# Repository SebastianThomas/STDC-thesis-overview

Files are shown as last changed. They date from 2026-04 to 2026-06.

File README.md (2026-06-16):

# Linear-Exponential Algorithm-based Open Source Dive Computer

## Cloning this repository

To ensure all submodules are available locally, use the following command to 
check out the files: 

```bash
git clone --recurse-submodules git@git.ee.ethz.ch:pbl/FS2026/sebastian_thomas_653.git
```

## File Structure

```bash
.
├── 01_report
├── 02_presentation
├── KiCad
├── STDC_C
├── STDC-Ordering
├── STDC-Ordering.zip
├── STDC-STM32-rs
├── STDC-thalmann
└── README.md
```

## The `STDC-STM32-rs` project

This is the embedded firmware implementation, it is the module required to 
reproduce the experimental results, and to run the firmware on the PCB. 

### Setup environment

1. [Install Rust](https://rust-lang.org/tools/install/)
2. [Install just](https://just.systems/man/en/installation.html)
3. Add target for the embedded STM32 environment: `rustup target add thumbv7em-none-eabihf`

### Running code

It contains a `DEBUGGING.md` file with all the necessary information to debug
an application on the PCB and reproduce simulation results.

A `Justfile` is provided for convenience, it contains all required commands for
simulation, embedding, testing, CI, compiling and checking (without compiling).

It is recommended to use a STM32L476Rxx chip, as this is what the code is
tested on. Power it using a 3.7V fixed DC power supply. Attach the STLink V3
to the computer and debug JTAG pads exposed next to the MCU on the PCB, and 
run any `just` recipe that embeds software onto the MCU. After flashing, a 
terminal window will popup on top of the current session.

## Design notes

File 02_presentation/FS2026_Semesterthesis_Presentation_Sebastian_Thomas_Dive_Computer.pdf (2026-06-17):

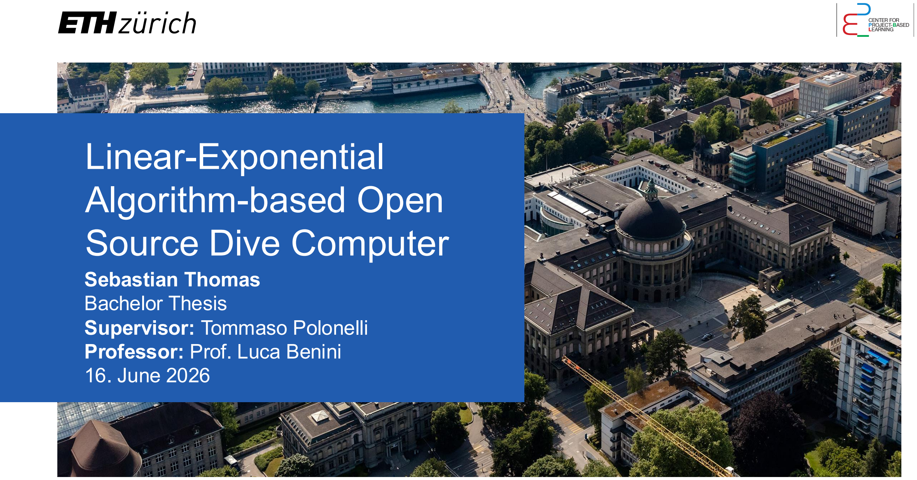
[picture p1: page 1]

# Linear-Exponential Algorithm-based Open Source Dive Computer

# Sebastian Thomas Bachelor Thesis Supervisor: Tommaso Polonelli Professor: Prof. Luca Benini 16. June 2026

# Introduction: Diving & Hyperbaric Environments

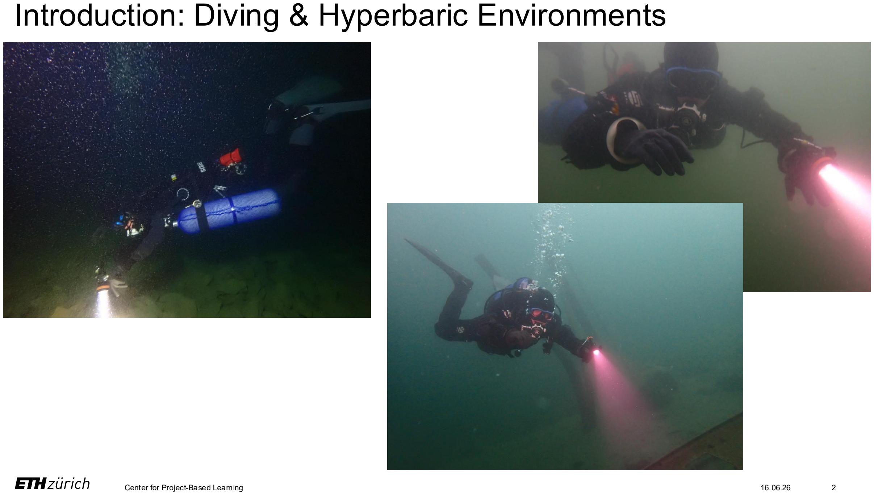
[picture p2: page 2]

Center for Project-Based Learning | 16.06.26 | 2

# Introduction: Diving & Hyperbaric Environments

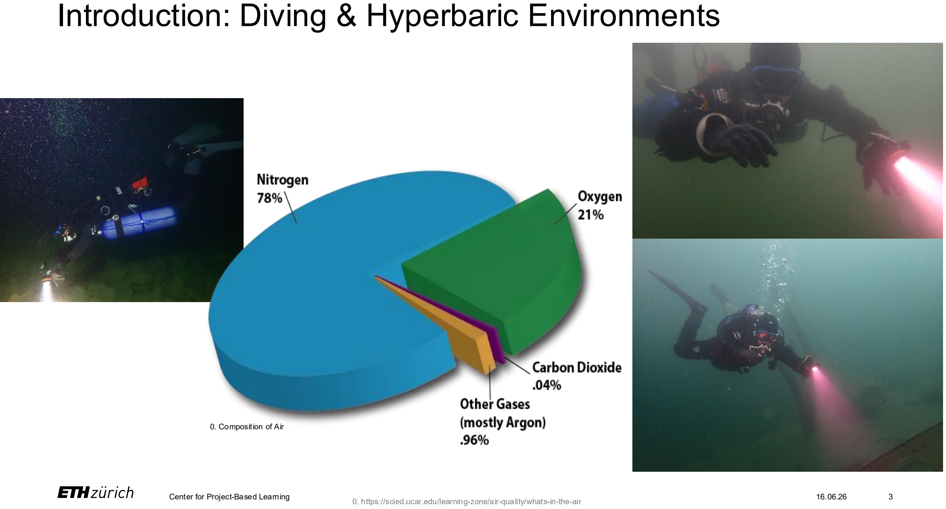
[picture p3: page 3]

0. Composition of Air
0. https://scied.ucar.edu/learning-zone/air-quality/whats-in-the-air

# Introduction: Dive Computers

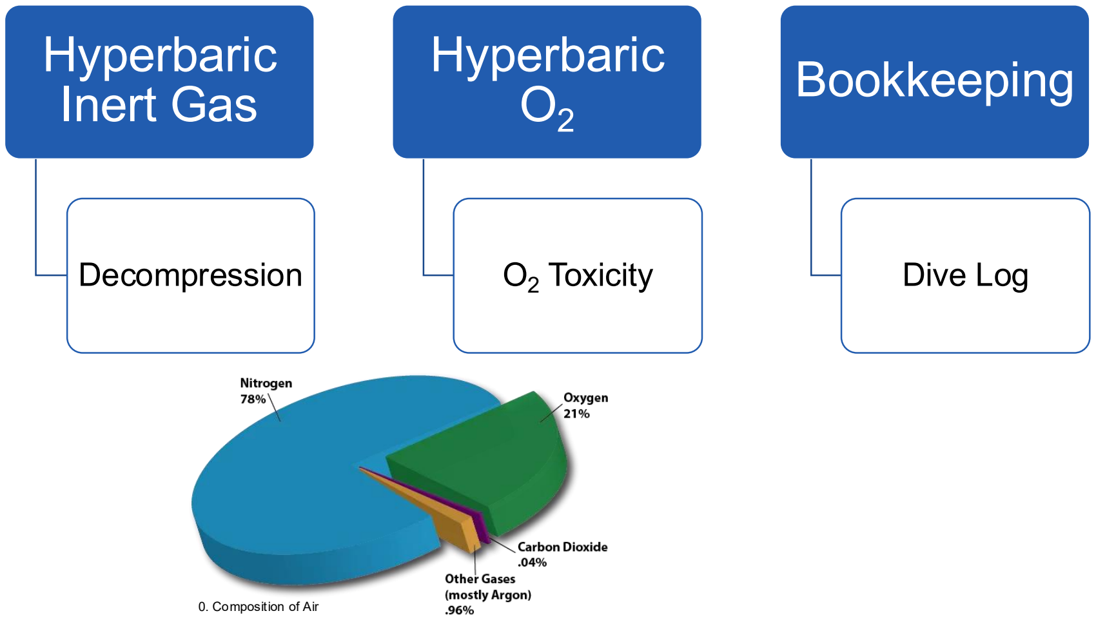
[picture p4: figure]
Hyperbaric Inert Gas; Decompression; Hyperbaric O2; O2 Toxicity; Bookkeeping; Dive Log; 0. Composition of Air

0. https://scied.ucar.edu/learning-zone/air-quality/whats-in-the-air

# Introduction: Dive Computers

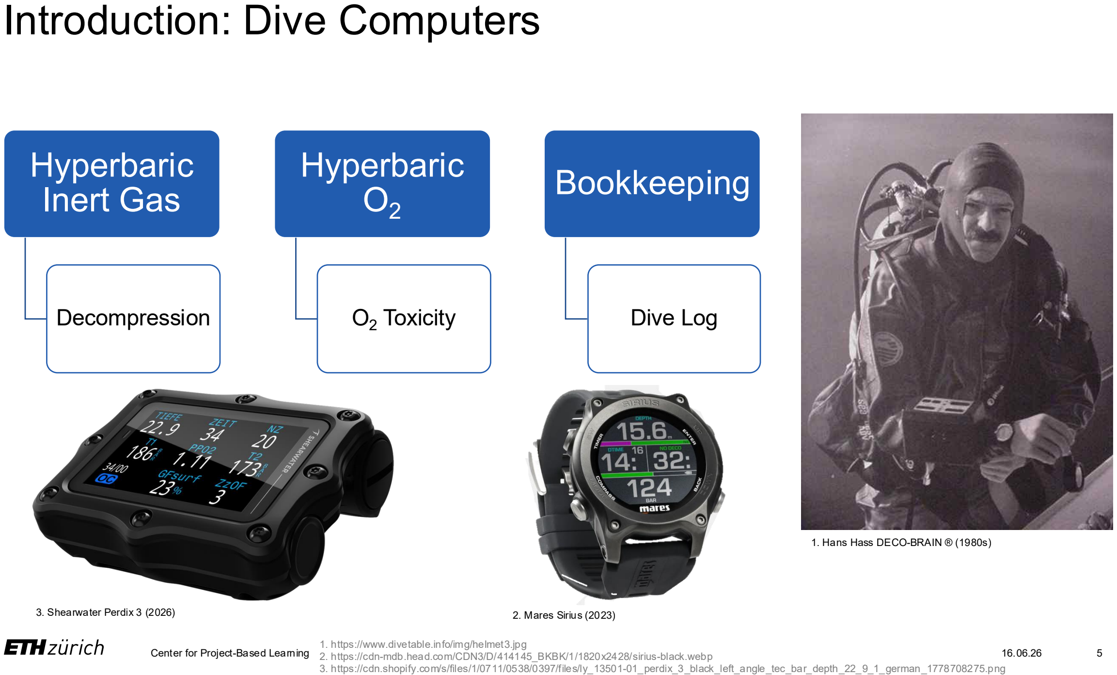
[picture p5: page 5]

# Hyperbaric Inert Gas

# Decompression

# Hyperbaric

O2

# O2 Toxicity

# Bookkeeping

# Dive Log

1. Hans Hass DECO-BRAIN ® (1980s)
2. Mares Sirius (2023)
1. https://www.divetable.info/img/helmet3.jpg
2. https://cdn-mdb.head.com/CDN3/D/414145_BKBK/1/1820x2428/sirius-black.webp
3. https://cdn.shopify.com/s/files/1/0711/0538/0397/files/ly_13501-01_perdix_3_black_left_angle_tec_bar_depth_22_9_1_german_1778708275.png
3. Shearwater Perdix 3 (2026)

# Problem Description

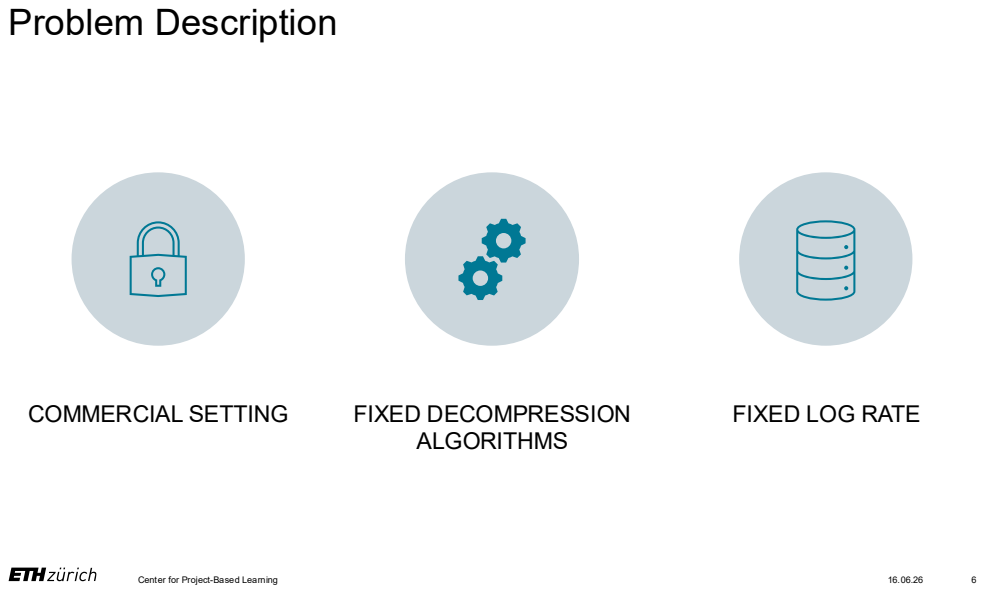
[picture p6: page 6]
COMMERCIAL SETTING; FIXED DECOMPRESSION; ALGORITHMS

FIXED LOG RATE

# Thesis Goals

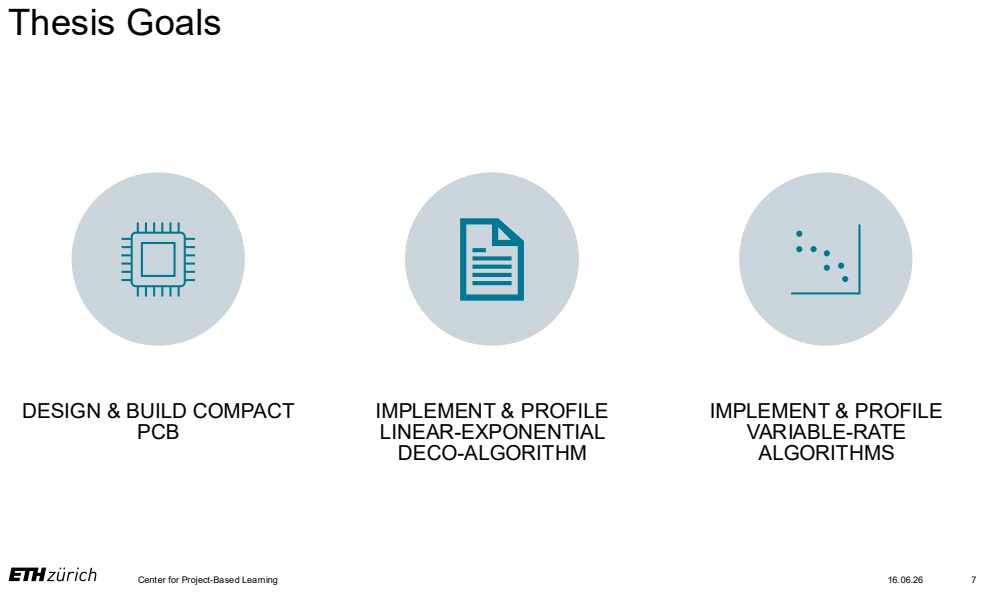
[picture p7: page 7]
PCB; IMPLEMENT & PROFILE LINEAR-EXPONENTIAL DECO-ALGORITHM; IMPLEMENT & PROFILE VARIABLE-RATE ALGORITHMS

DESIGN & BUILD COMPACT

# Background: Decompression Algorithms

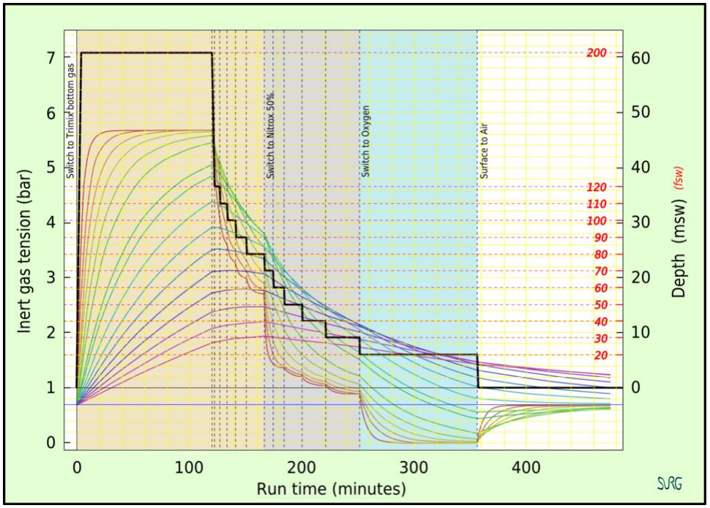
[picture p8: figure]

5. https://en.wikipedia.org/wiki/File:Inert_gas_tensions_in_the_tissue_compartments_during_a_decompression_dive.png
5. Example Decompression Model

# Background: Hyperbaric Environments

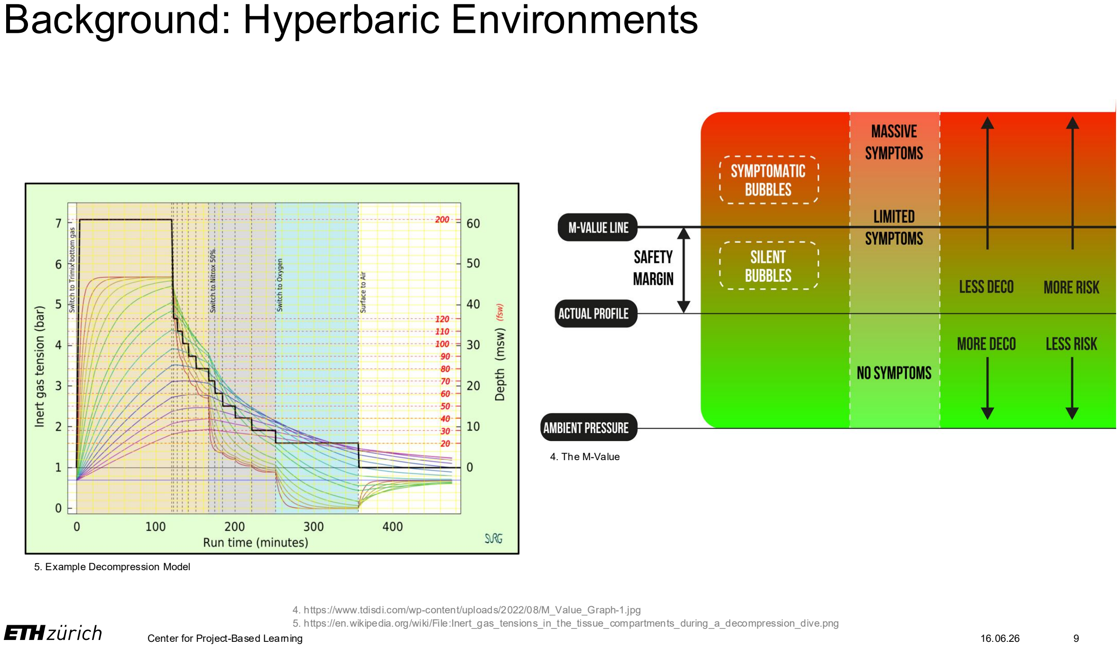
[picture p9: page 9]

4. The M-Value
4. https://www.tdisdi.com/wp-content/uploads/2022/08/M_Value_Graph-1.jpg
5. https://en.wikipedia.org/wiki/File:Inert_gas_tensions_in_the_tissue_compartments_during_a_decompression_dive.png
5. Example Decompression Model

# Implementation

# Implementation: Hardware

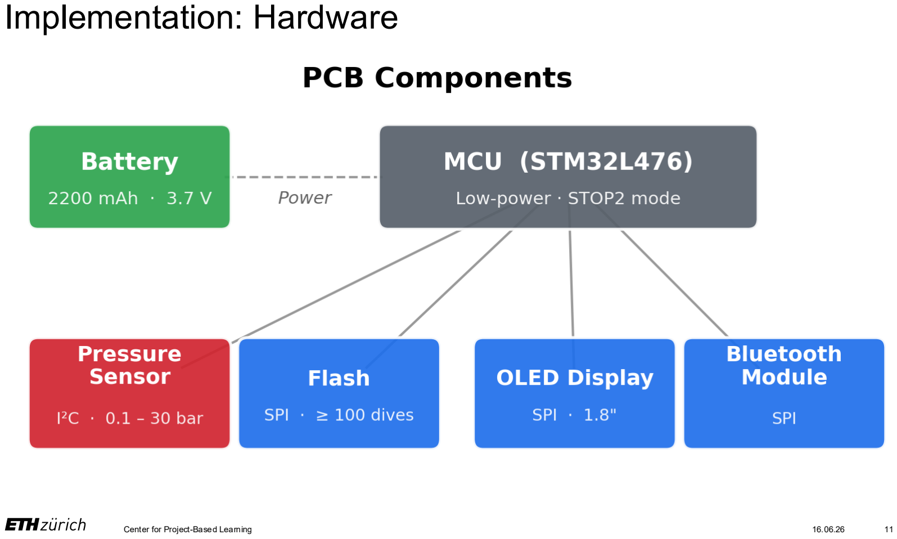
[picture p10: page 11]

# Implementation: Hardware

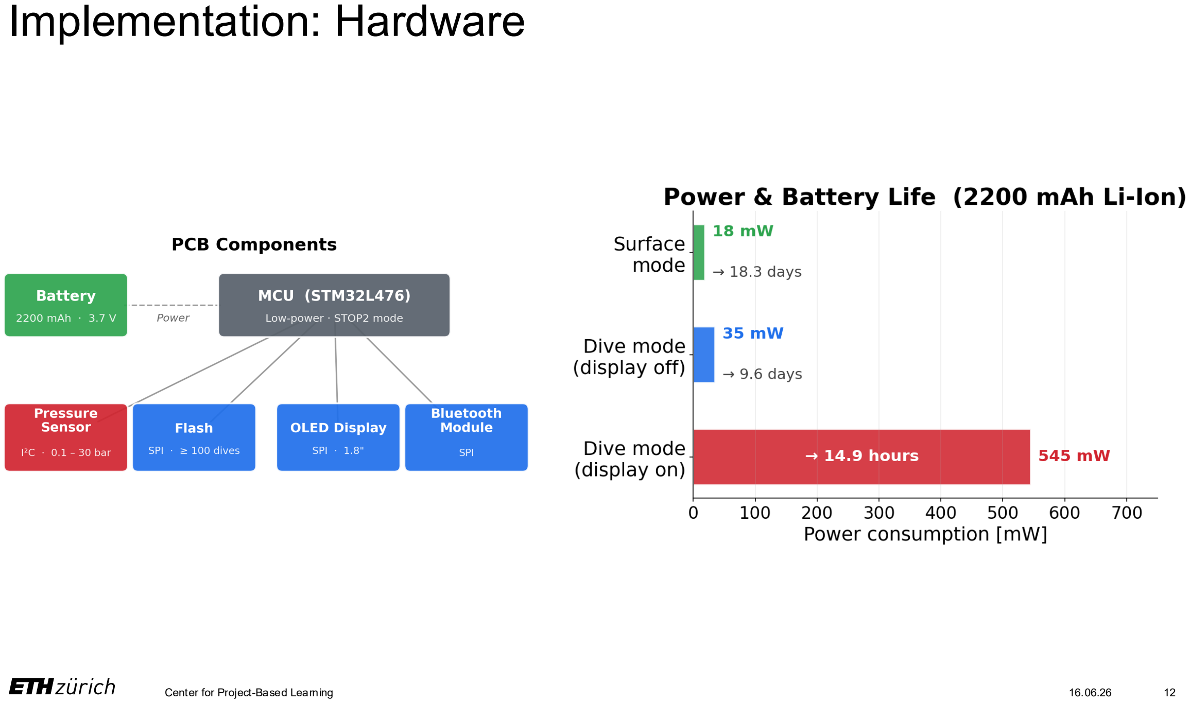
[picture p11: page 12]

# Implementation: Hardware

# - MCU: Low-Power

# - Battery: 18 days / 15 dive hours

# - Pressure sensor: 0.1-30 bar

# - External Bluetooth module

# - Large, bright, OLED display

# - Flash for >100 dives

# MCU

# Battery & Charging

# Pressure Sensor

# BLE

# Display

# Flash

# Implementation: Hardware - Components

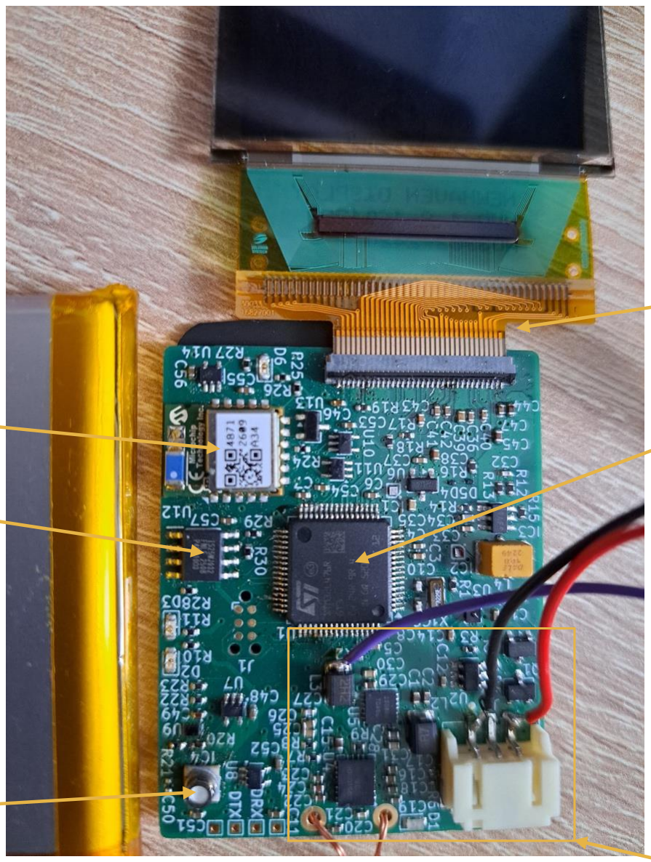
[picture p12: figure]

# - MCU: STM32L476

# - Connector for 3.7V Li-ion battery (2200mAh) − Wireless charging, battery protection

# - MS5849-30BA pressure sensor

# - RN-4871 BLE module

# - 1.8’’ NHD OLED-Display

# - 4MB Flash

# MCU

# Battery & Charging

# Pressure Sensor

# BLE

# Display

# Flash

# Implementation: Hardware – Power Distribution

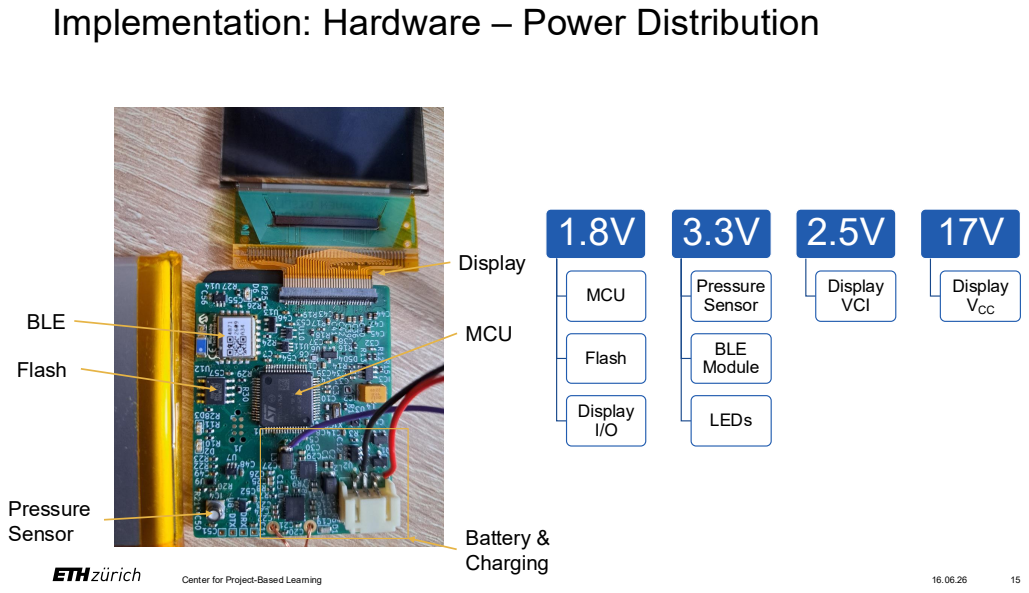
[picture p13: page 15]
MCU; Flash; Display I/O; Pressure Sensor; BLE Module; LEDs; Display VCI; Display; VCC; Battery & Charging; BLE

# Implementation: PCB Layout

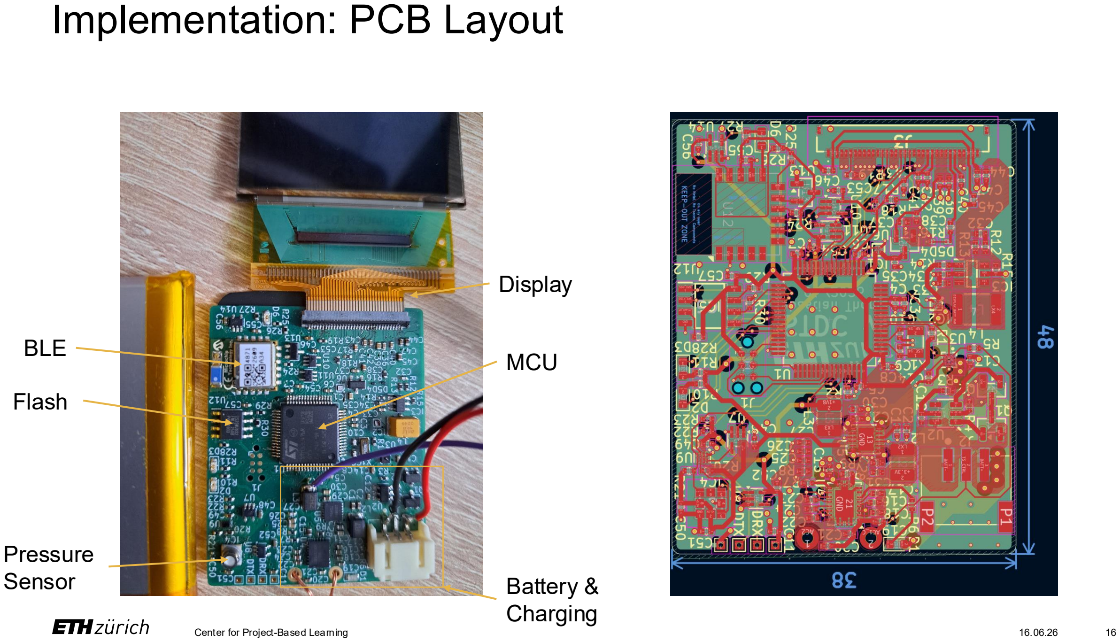
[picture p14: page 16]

# MCU

# Battery & Charging

# Pressure Sensor

# BLE

# Display

# Flash

# Example: Acrylic Enclosure

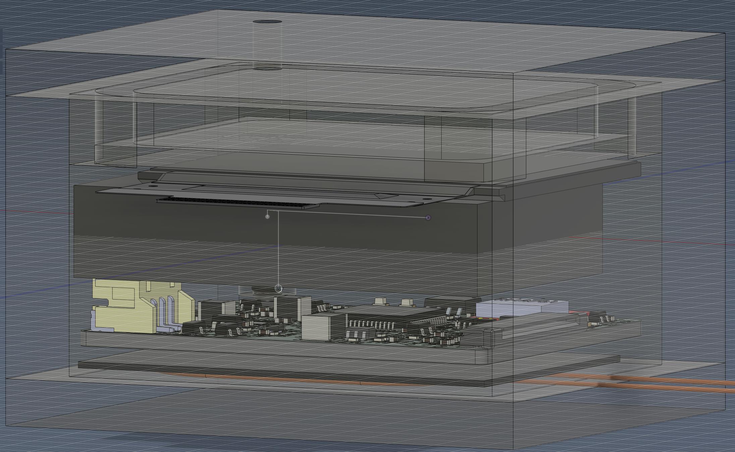
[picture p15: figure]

# Implementation: Linear-Exponential decompression algorithm

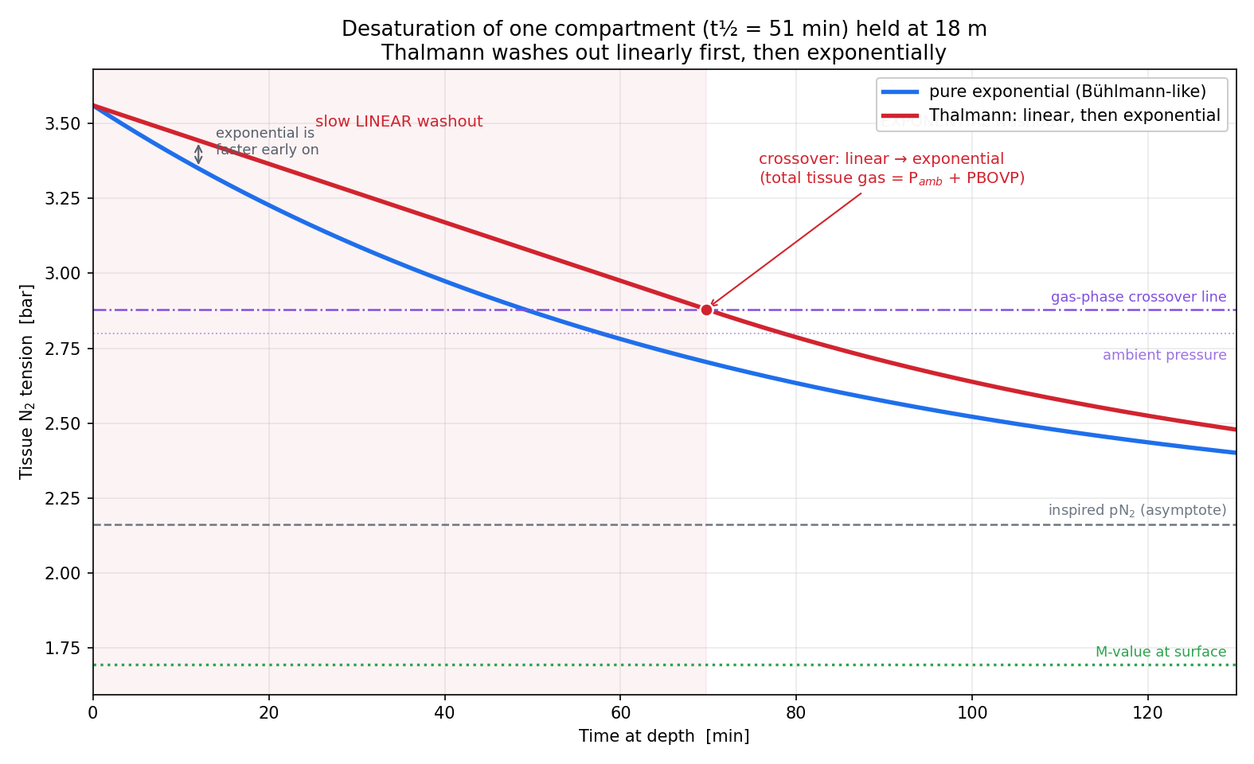
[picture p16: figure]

# Implementation: Variable-rate algorithms

# - Additive Increase (AI), Multiplicative Decrease (MD – change)

| DiffAimdRateAlgorithm | DynamicDiffAimdRateAlgorithm
change | δv δt | δv δt or fixed threshold
Cycles | ~1730 | ~1850

# Results & Discussion

# Results: Variable-rate algorithms – decompression models

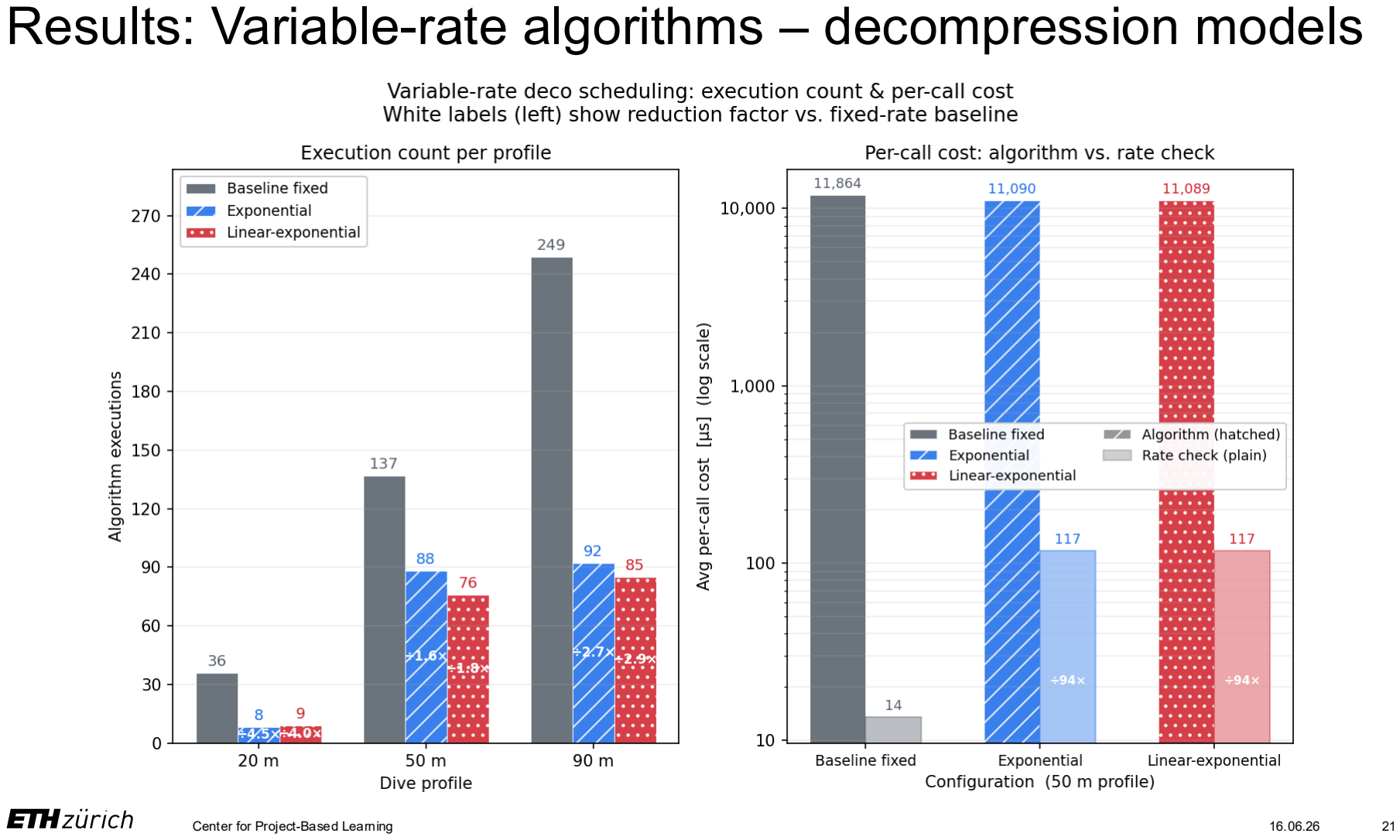
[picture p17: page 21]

# Results: Variable-rate algorithms – O2Tox calculation

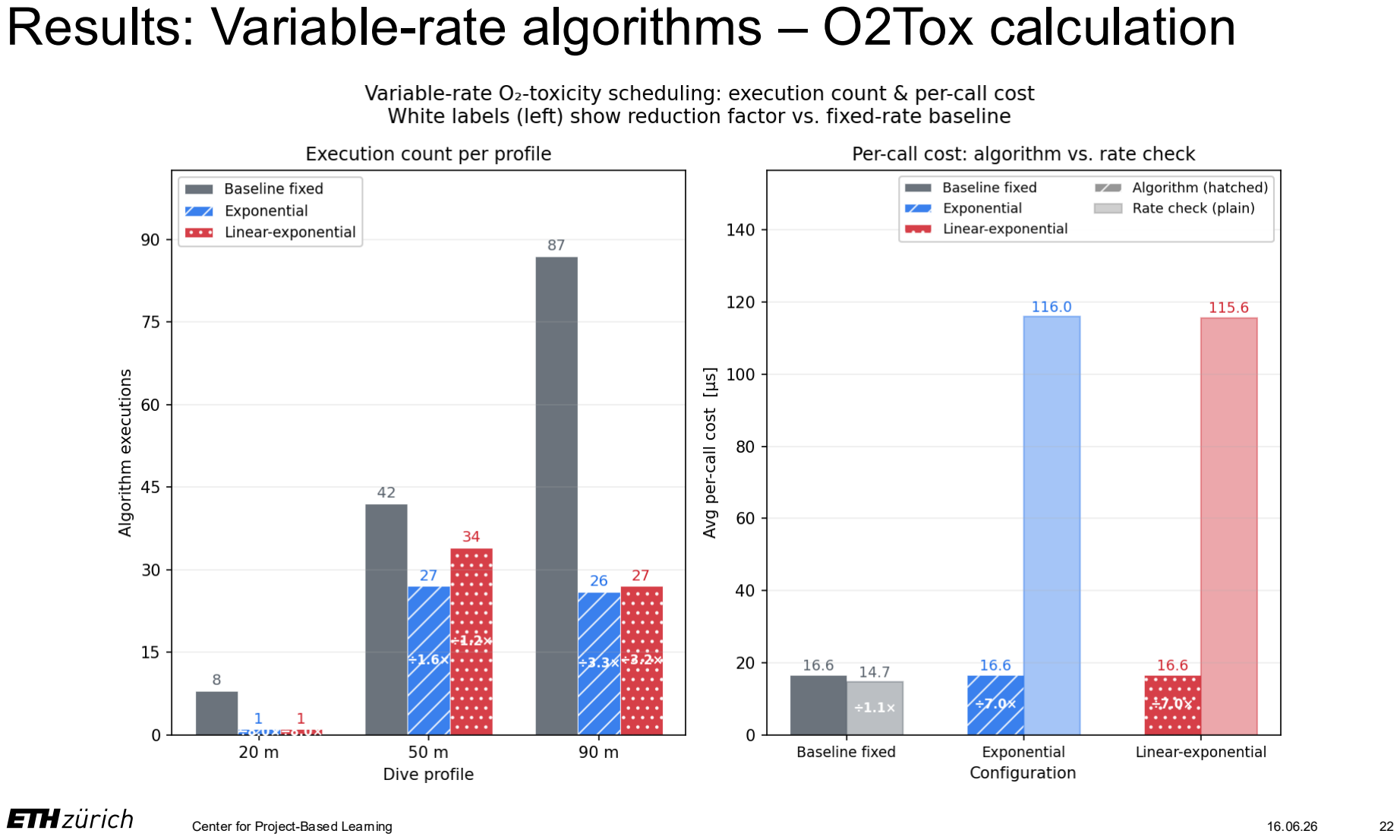
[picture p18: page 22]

# Discussion: Variable-rate for diving algorithms

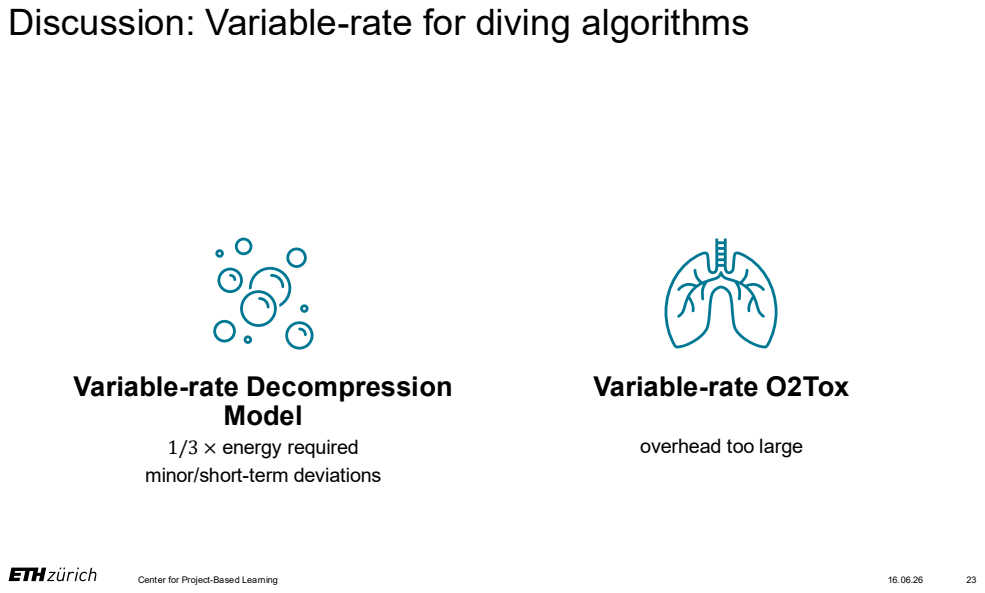
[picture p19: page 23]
Model; Variable-rate O2Tox

Variable-rate Decompression

1 over 3 times
1/3 × energy required
minor/short-term deviations

overhead too large

# Results: Variable-rate algorithms – Dive Log to Flash

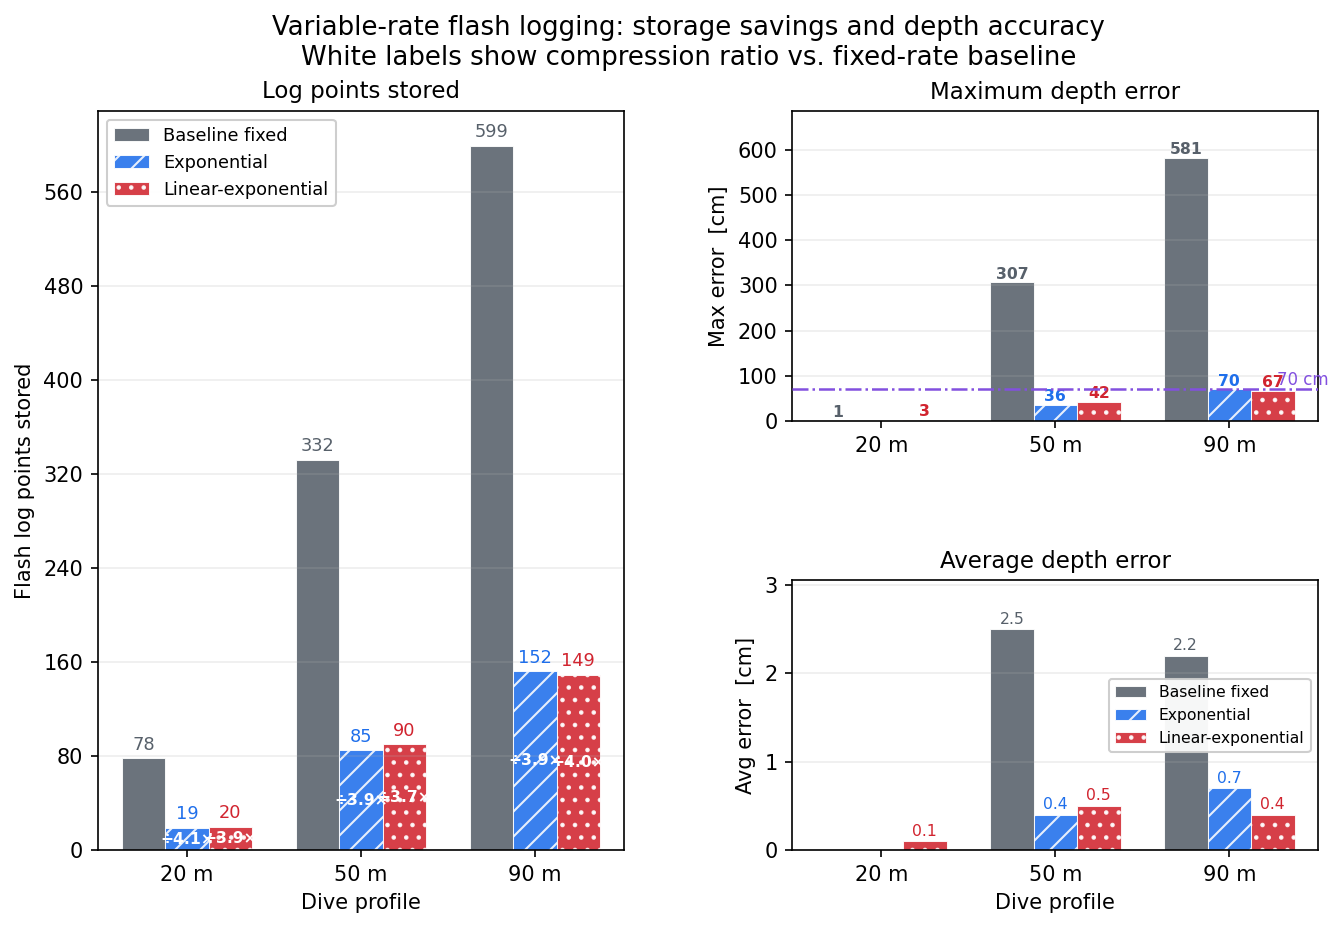
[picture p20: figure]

# Results: Linear-exponential decompression algorithm

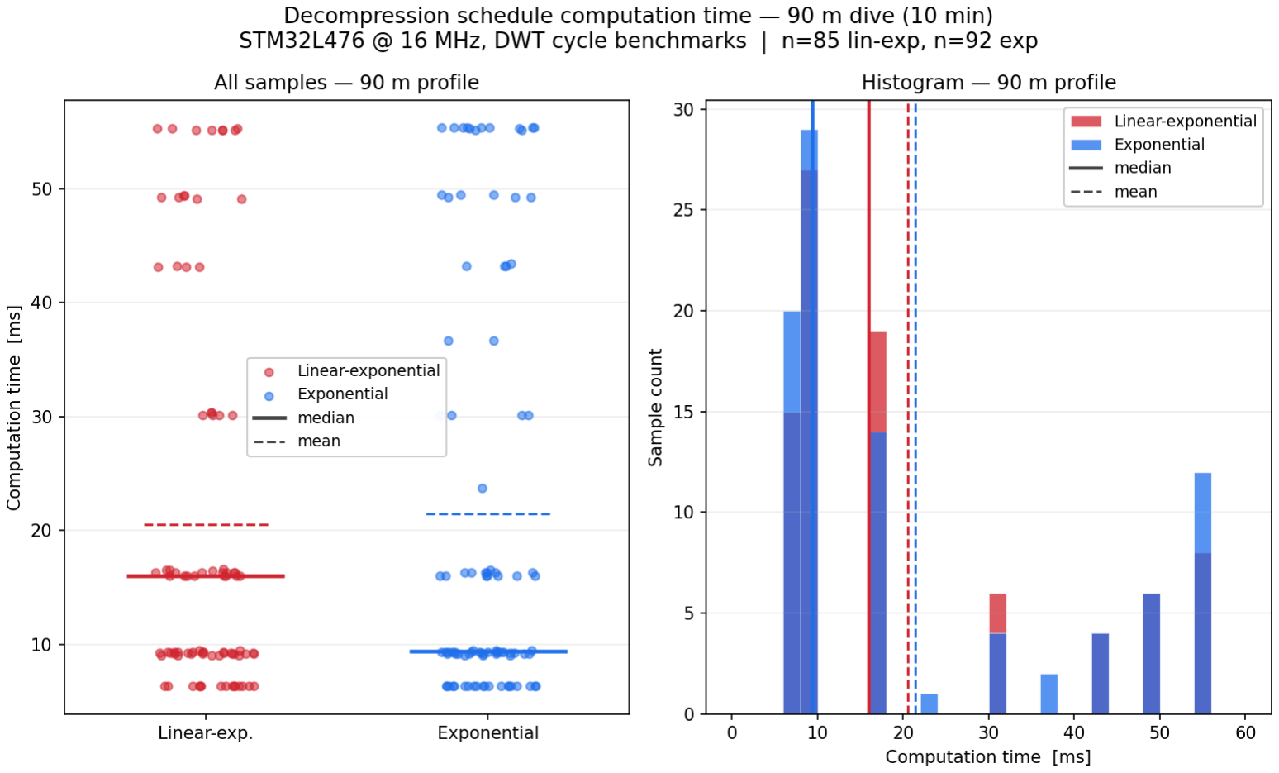
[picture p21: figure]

# Discussion: Linear-exponential algorithms & Variable-rate Flash logging

# - Linear-exponential decompression algorithm − As expected, customizability

# - Variable-rate Dive Log to Flash − Space Reduction: 3.6 ×-4.1 ×

# Conclusion

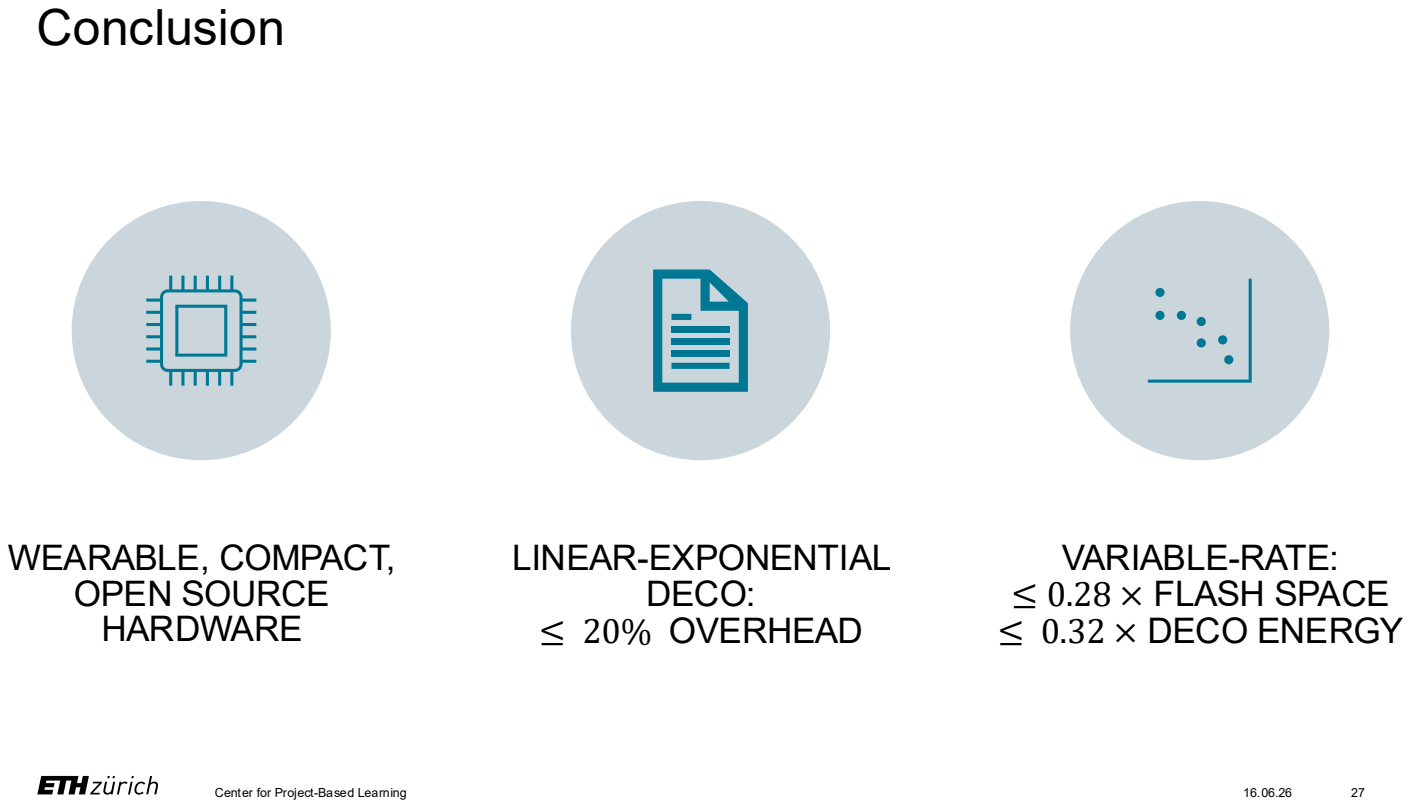
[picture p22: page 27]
WEARABLE, COMPACT, OPEN SOURCE HARDWARE; LINEAR-EXPONENTIAL DECO:

VARIABLE-RATE:
≤ 0.28 × FLASH SPACE
times
≤ 0.32 × DECO ENERGY
less than or equal to , 0.32

less than or equal to 0.28

less than or equal to , 20%
≤ 20% OVERHEAD

# Future Work

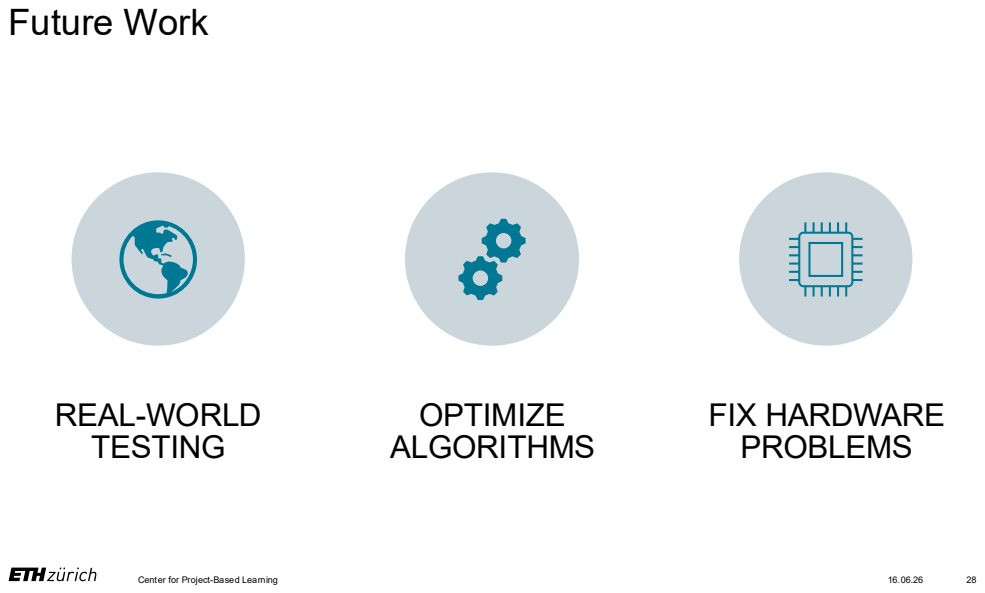
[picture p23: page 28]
REAL-WORLD TESTING; OPTIMIZE ALGORITHMS; FIX HARDWARE PROBLEMS

# Figure References

# Fig. 0. UCAR Center for Science Education, https://scied.ucar.edu/learning-zone/air-

quality/whats (https://scied.ucar.edu/learning-zone/air-quality/whats-in-the-air)- (https://scied.ucar.edu/learning-zone/air-quality/whats-in-the-air)in (https://scied.ucar.edu/learning-zone/air-quality/whats-in-the-air)- (https://scied.ucar.edu/learning-zone/air-quality/whats-in-the-air)the (https://scied.ucar.edu/learning-zone/air-quality/whats-in-the-air)- (https://scied.ucar.edu/learning-zone/air-quality/whats-in-the-air)air, (https://scied.ucar.edu/learning-zone/air-quality/whats-in-the-air) last accessed: 10.06.2026

Fig. 1. Tauch-Simulationssoftware und das D³ Archiv,

# https://www.divetable.info/img/helmet3.jpg, last accessed: 09.06.2026

Fig. 2. Mares (Sirius Black), https://cdn (https://cdn-mdb.head.com/CDN3/D/414145_BKBK/1/1820x2428/sirius-black.webp)-mdb.head.com/CDN3/D/414145_BKBK/1/1820x2428/sirius (https://cdn-mdb.head.com/CDN3/D/414145_BKBK/1/1820x2428/sirius-black.webp)- (https://cdn-mdb.head.com/CDN3/D/414145_BKBK/1/1820x2428/sirius-black.webp)black.webp, (https://cdn-mdb.head.com/CDN3/D/414145_BKBK/1/1820x2428/sirius-black.webp) last accessed: 09.06.2026

Fig. 3. Shearwater Electronics, 2026, https://shearwater.com/en-sw/products/perdix-3, last

# accessed: 09.06.2026

Fig. 4. TDI/SDI: Decompression, 2024, https://www.tdisdi.com/wp (https://www.tdisdi.com/wp-content/uploads/2022/08/M_Value_Graph-1.jpg)-content/uploads/2022/08/M_Value_Graph (https://www.tdisdi.com/wp-content/uploads/2022/08/M_Value_Graph-1.jpg)- (https://www.tdisdi.com/wp-content/uploads/2022/08/M_Value_Graph-1.jpg)1.jpg, (https://www.tdisdi.com/wp-content/uploads/2022/08/M_Value_Graph-1.jpg) last accessed: 08.06.2026

Fig. 5. Wikimedia Foundation: Decompression theory (based on: Eric Maiken, 2004), https://en.wikipedia.org/wiki/File:Inert_gas_tensions_in_the_tissue_compartments_during_a_decompression_dive.png, (https://en.wikipedia.org/wiki/File:Inert_gas_tensions_in_the_tissue_compartments_during_a_decompression_dive.png) last accessed: 09.06.2026

# Sebastian Thomas Bachelor Thesis tsebastian@student.ethz.ch

# ETH Zürich Center for Project-Based Learning ETF F109 Sternwartstrasse 7 8092 Zürich

# www.pbl.ee.ethz.ch

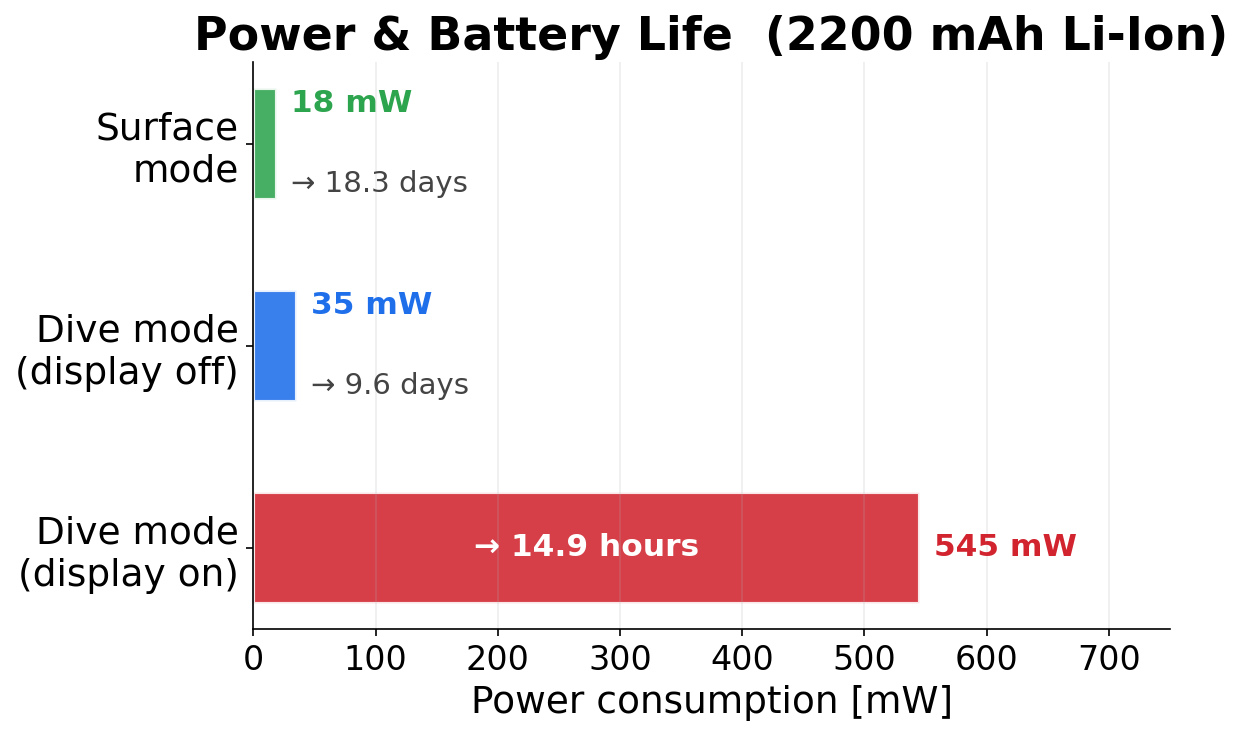
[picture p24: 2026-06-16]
02_presentation/figures/hardware/fig_pcb_power.png

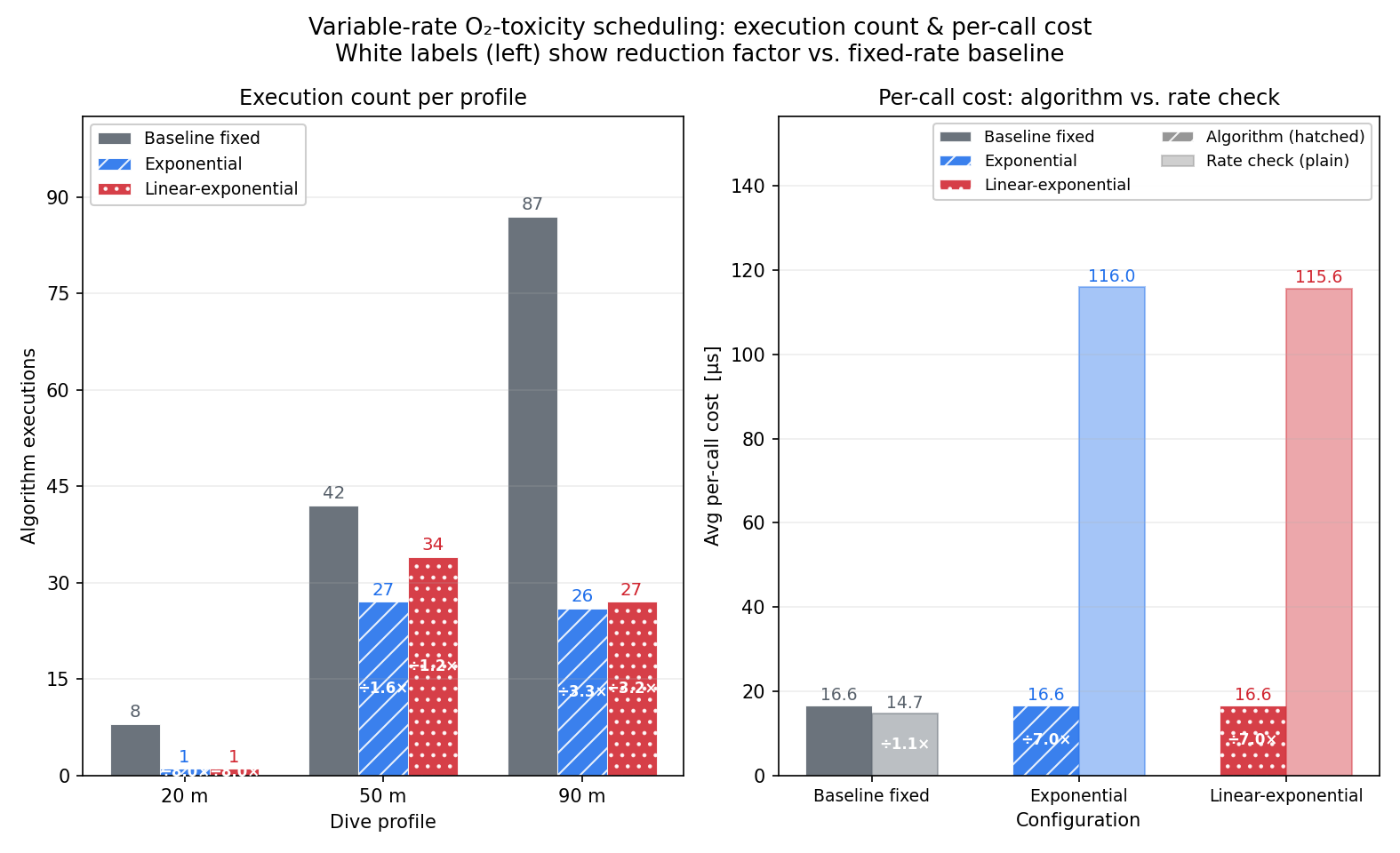
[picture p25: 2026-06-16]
02_presentation/figures/timing/fig_rate_o2tox.png

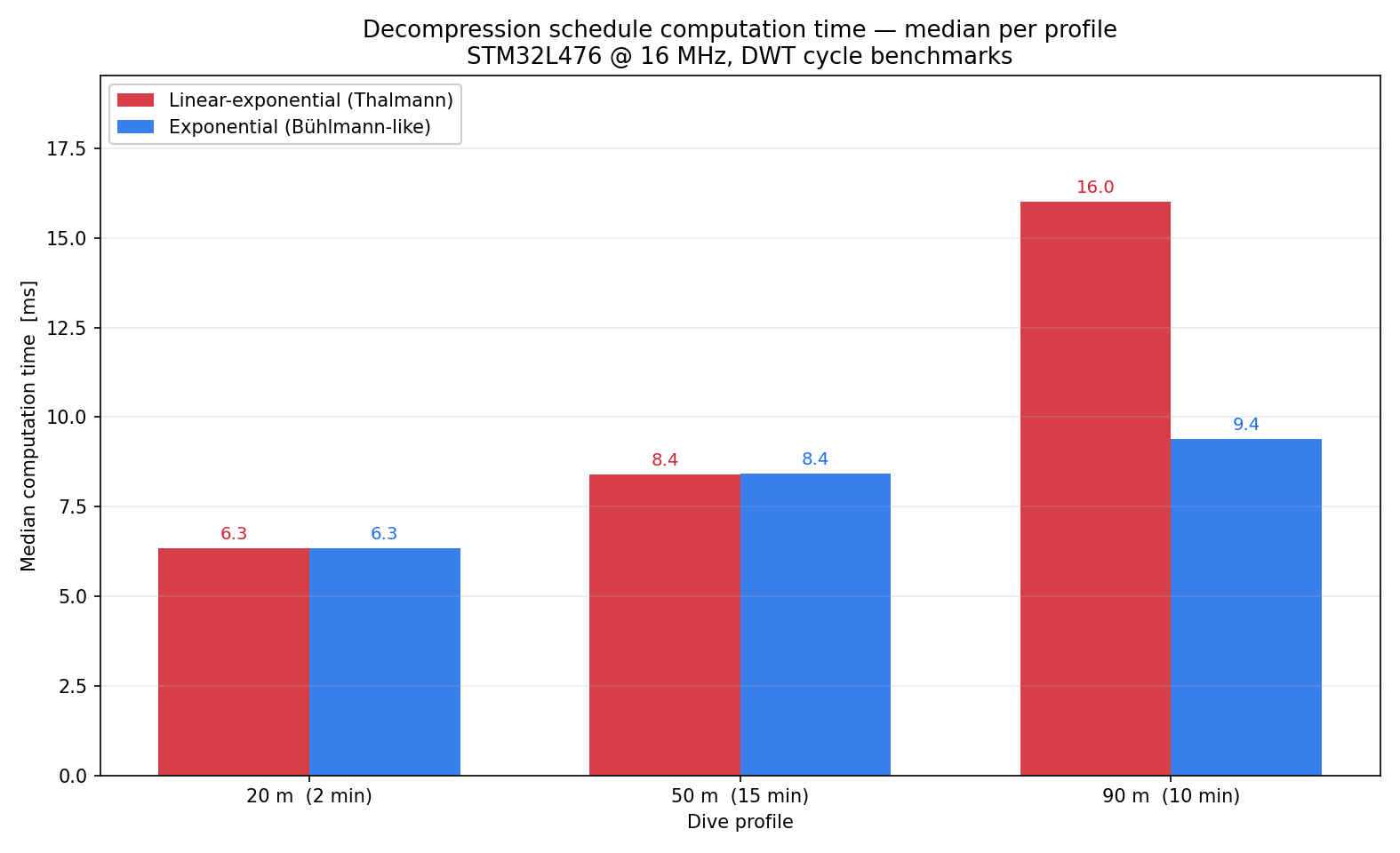
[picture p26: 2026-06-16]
02_presentation/figures/timing/fig_timing_median.png

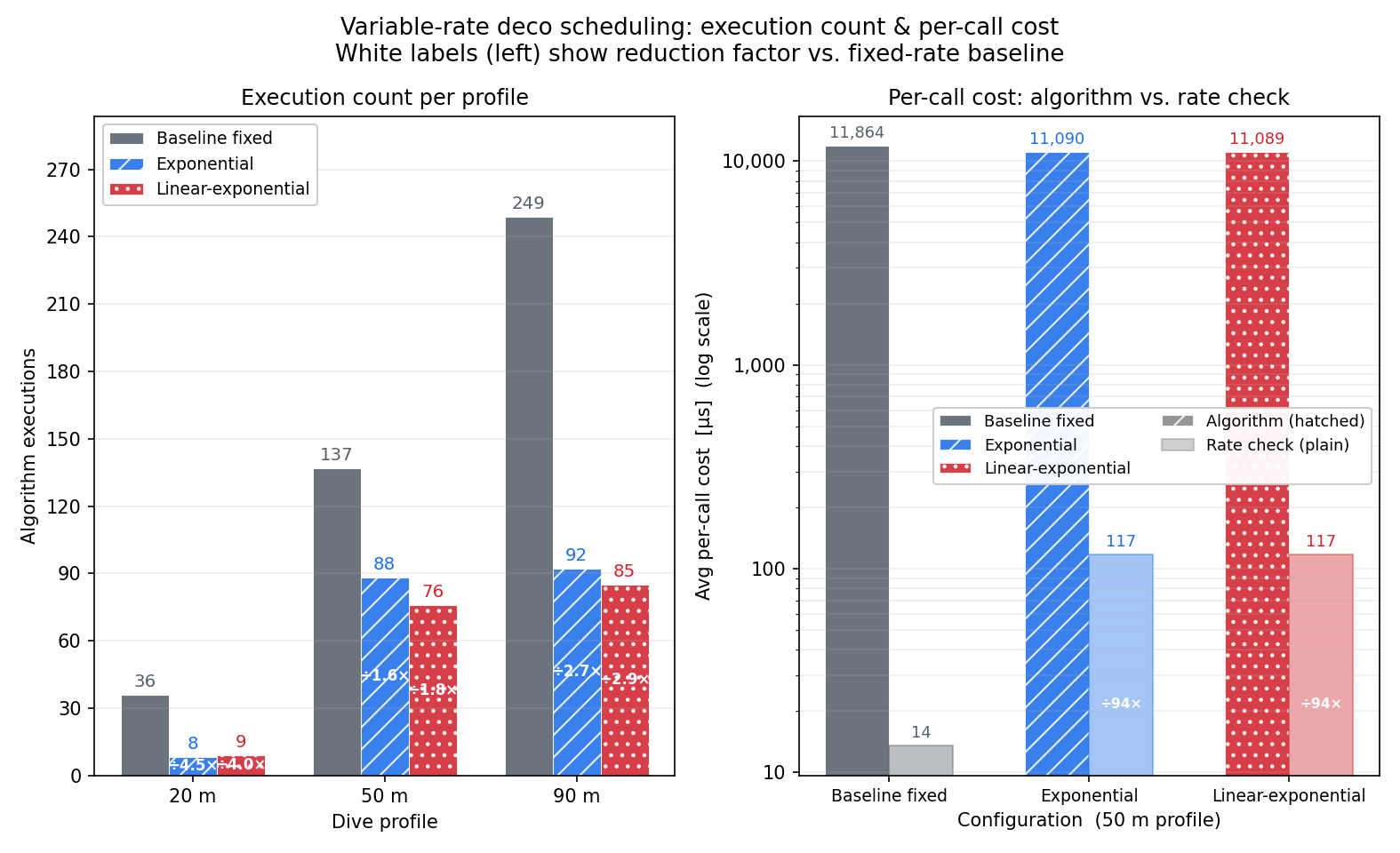
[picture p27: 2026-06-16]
02_presentation/figures/timing/fig_rate_deco.png

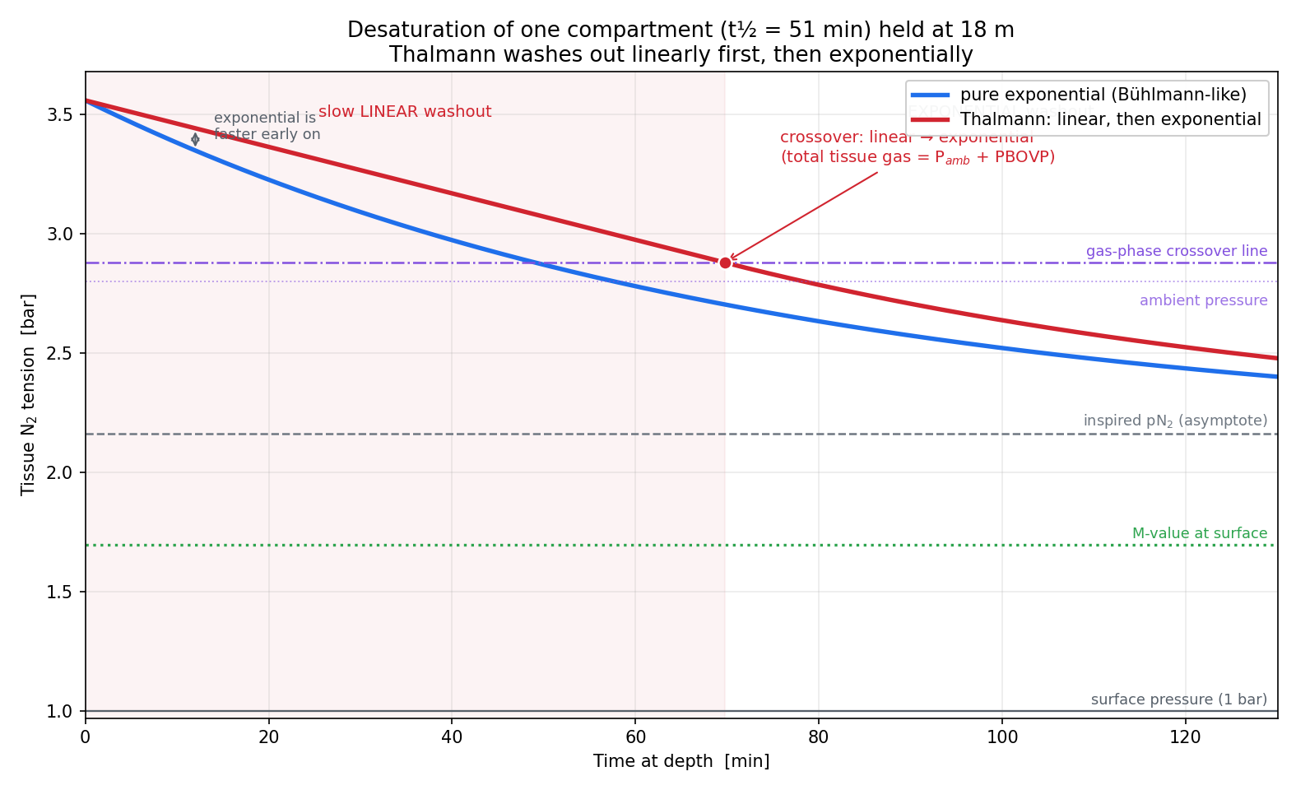
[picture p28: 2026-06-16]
02_presentation/figures/saturation/fig_desat_crossover.png

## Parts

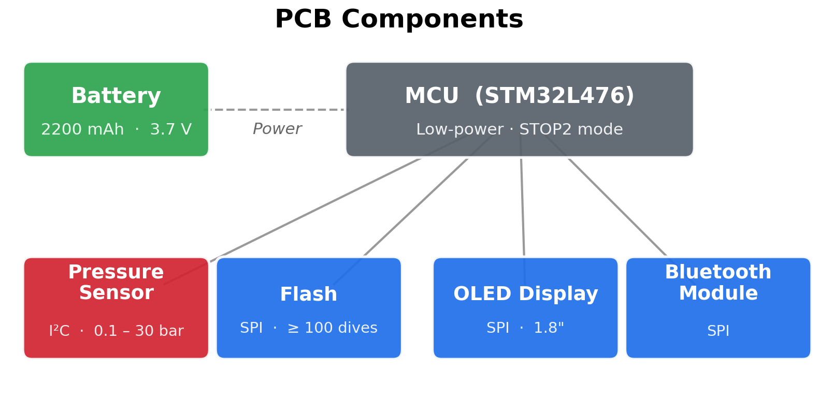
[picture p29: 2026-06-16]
02_presentation/figures/hardware/fig_pcb_components.png

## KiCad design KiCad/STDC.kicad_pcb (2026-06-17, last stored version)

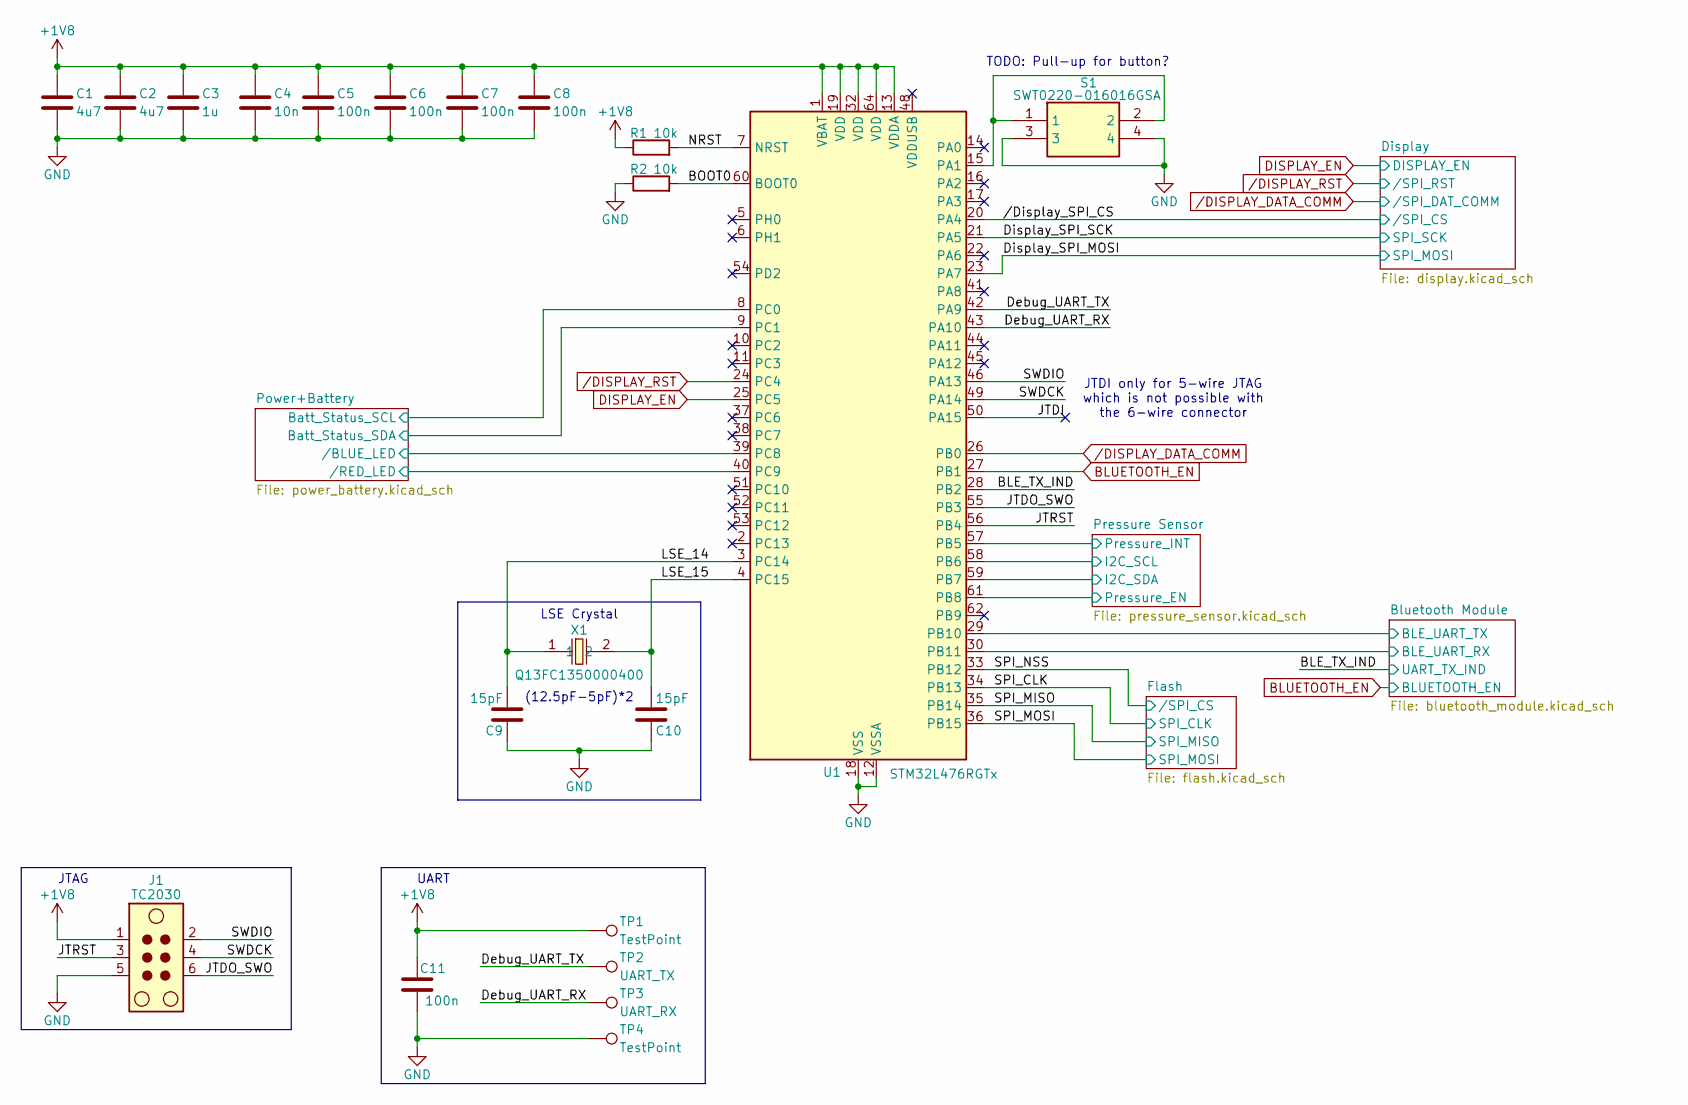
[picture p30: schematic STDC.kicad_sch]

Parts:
C1, C2: 4u7; C_0402_1005Metric
C3: 1u; C_0402_1005Metric
C4: 10n; C_0402_1005Metric
C5, C6, C7, C8, C11: 100n; C_0402_1005Metric
C9, C10: 15pF; C_0402_1005Metric
J1: TC2030; Tag-Connect_TC2030-IDC-NL_2x03_P1.27mm_Vertical
R1, R2: 10k; R_0402_1005Metric
S1: SWT0220-016016GSA; SWT0220016016GSA; Mouser Part Number 640-SWT0220016016GSA
TP1, TP4: TestPoint; TestPoint_THTPad_1.0x1.0mm_Drill0.5mm
TP2: UART_TX; TestPoint_THTPad_1.0x1.0mm_Drill0.5mm
TP3: UART_RX; TestPoint_THTPad_1.0x1.0mm_Drill0.5mm
U1: STM32L476RGTx; LQFP-64_10x10mm_P0.5mm
X1: Q13FC1350000400; Crystal_SMD_3215-2Pin_3.2x1.5mm; LCSC Part C32346

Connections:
+1V8: C1.1, C2.1, C3.1, C4.1, C5.1, C6.1, C7.1, C8.1, C11.1, J1.1, R1.1, TP1.1, U1.1 (VBAT), U1.13 (VDDA), U1.19 (VDD), U1.32 (VDD), U1.64 (VDD); also elsewhere on the board
/BLE_TX_IND: U1.28 (PB2); also elsewhere on the board
/BOOT0: R2.2, U1.60 (BOOT0)
/Bluetooth Module/BLE_UART_RX: U1.30 (PB11); also elsewhere on the board
/Bluetooth Module/BLE_UART_TX: U1.29 (PB10); also elsewhere on the board
/Debug_UART_RX: TP3.1, U1.43 (PA10)
/Debug_UART_TX: TP2.1, U1.42 (PA9)
/Display_SPI_MOSI: U1.23 (PA7); also elsewhere on the board
/Display_SPI_SCK: U1.21 (PA5); also elsewhere on the board
/JTDI: U1.50 (PA15)
/JTDO_SWO: J1.6, U1.55 (PB3)
/JTRST: J1.3, U1.56 (PB4)
/LSE_14: C9.2, U1.3 (PC14), X1.1
/LSE_15: C10.2, U1.4 (PC15), X1.2
/NRST: R1.2, U1.7 (NRST)
/Power+Battery/Batt_Status_SCL: U1.8 (PC0); also elsewhere on the board
/Power+Battery/Batt_Status_SDA: U1.9 (PC1); also elsewhere on the board
/Power+Battery//BLUE_LED: U1.39 (PC8); also elsewhere on the board
/Power+Battery//RED_LED: U1.40 (PC9); also elsewhere on the board
/Pressure Sensor/I2C_SCL: U1.58 (PB6); also elsewhere on the board
/Pressure Sensor/I2C_SDA: U1.59 (PB7); also elsewhere on the board
/Pressure Sensor/Pressure_EN: U1.61 (PB8); also elsewhere on the board
/Pressure Sensor/Pressure_INT: U1.57 (PB5); also elsewhere on the board
/SPI_CLK: U1.34 (PB13); also elsewhere on the board
/SPI_MISO: U1.35 (PB14); also elsewhere on the board
/SPI_MOSI: U1.36 (PB15); also elsewhere on the board
/SPI_NSS: U1.33 (PB12); also elsewhere on the board
/SWDCK: J1.4, U1.49 (PA14)
/SWDIO: J1.2, U1.46 (PA13)
//Display_SPI_CS: U1.20 (PA4); also elsewhere on the board
DISPLAY_EN: U1.25 (PC5); also elsewhere on the board
GND: C1.2, C2.2, C3.2, C4.2, C5.2, C6.2, C7.2, C8.2, C9.1, C10.1, C11.2, J1.5, R2.1, S1.3, S1.4, TP4.1, U1.12 (VSSA), U1.18 (VSS), U1.31 (VSS), U1.47 (VSS), U1.63 (VSS); also elsewhere on the board
unnamed: S1.1, S1.2, U1.15 (PA1)
/DISPLAY_DATA_COMM: U1.26 (PB0); also elsewhere on the board
/DISPLAY_RST: U1.24 (PC4); also elsewhere on the board

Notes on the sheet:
JTDI only for 5-wire JTAG which is not possible with the 6-wire connector
UART
TODO: Pull-up for button?
JTAG
(12.5pF-5pF)*2
LSE Crystal

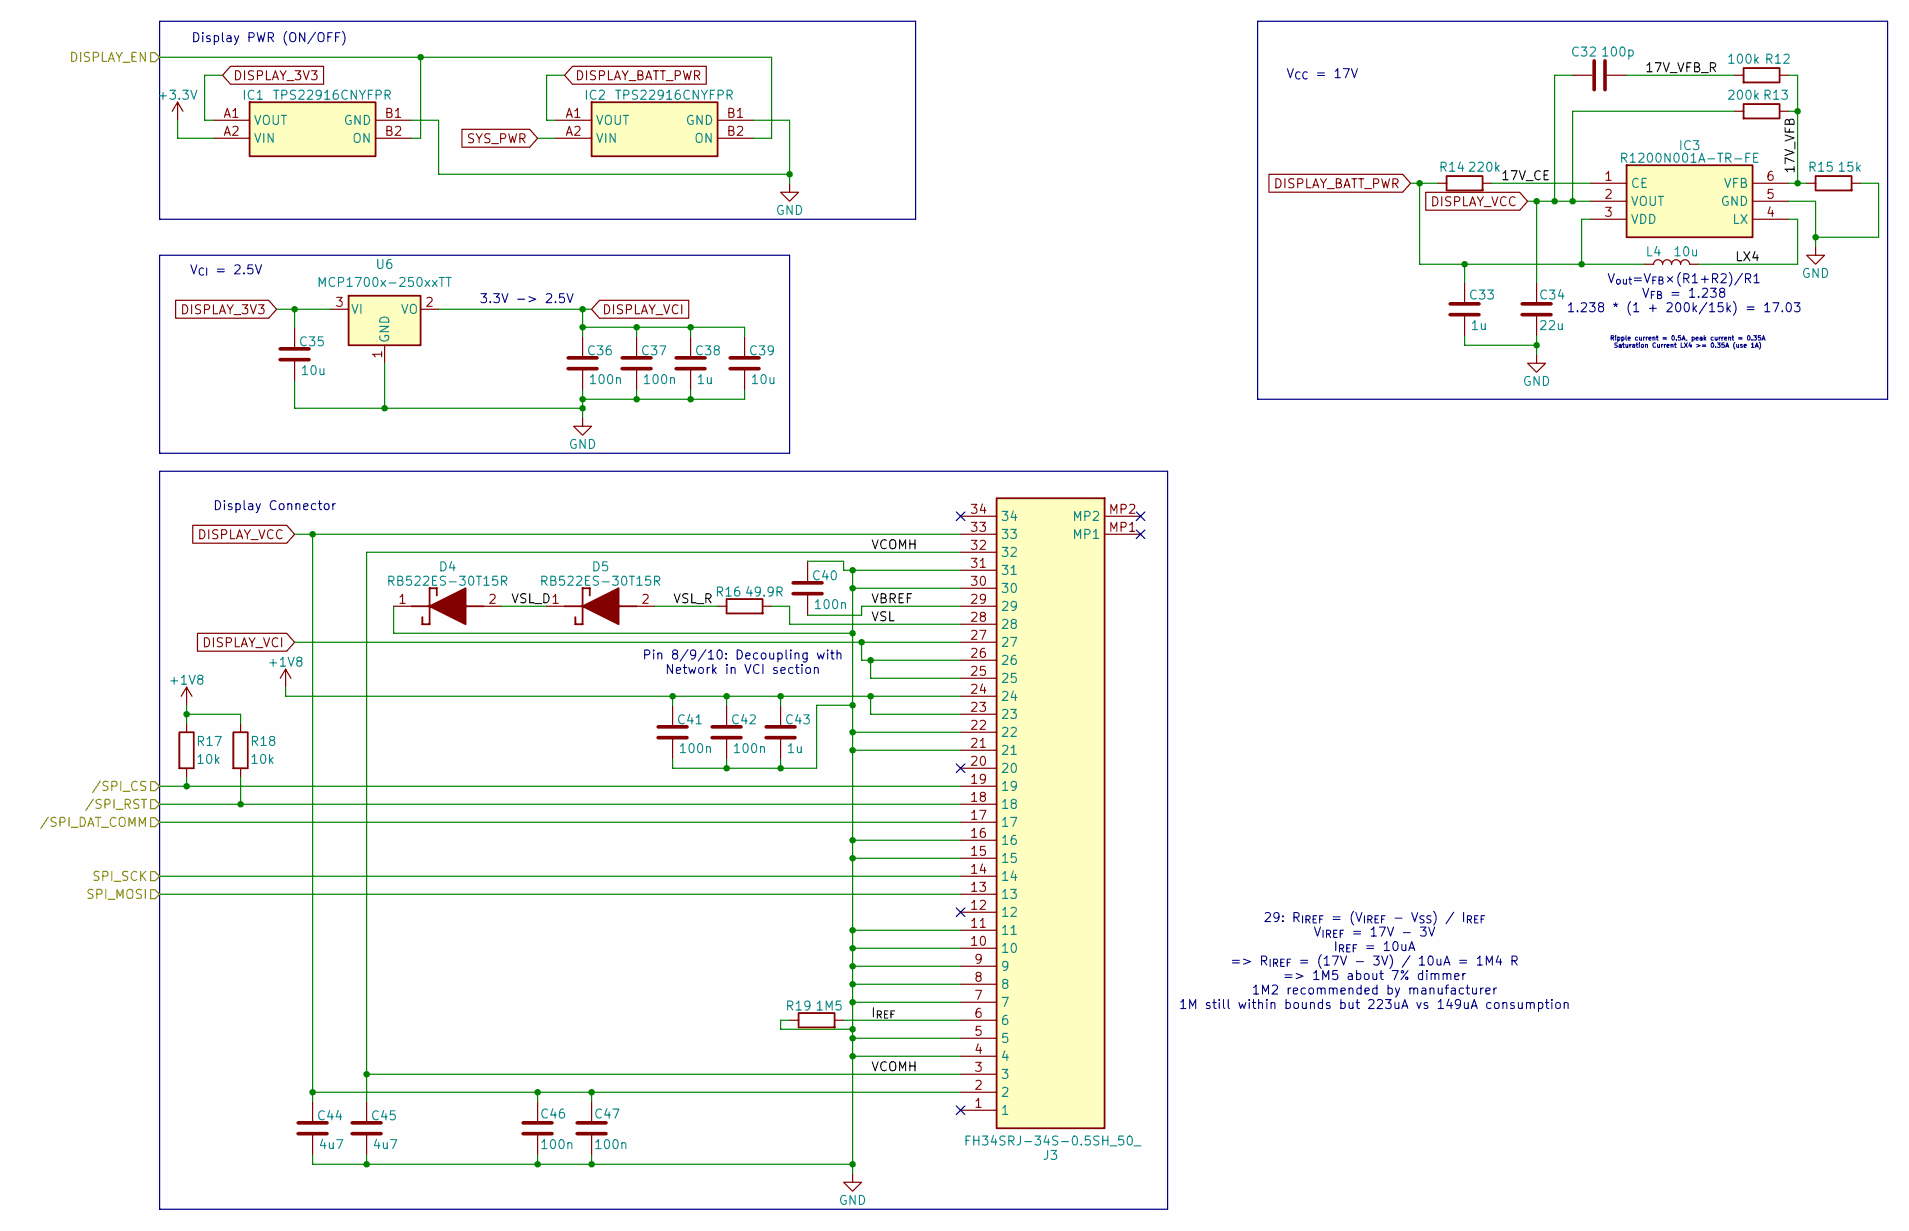
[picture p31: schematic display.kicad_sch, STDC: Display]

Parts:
C32: 100p; C_0402_1005Metric
C33, C38, C43: 1u; C_0402_1005Metric
C34: 22u; C_0402_1005Metric
C35, C39: 10u; C_0402_1005Metric
C36, C37, C40, C41, C42, C46, C47: 100n; C_0402_1005Metric
C44, C45: 4u7; C_0402_1005Metric
D4, D5: RB522ES-30T15R; RB522ES30; Mouser Part Number 755-RB522ES-30T15R
IC1, IC2: TPS22916CNYFPR; BGA4C40P2X2_78X78X50; Mouser Part Number 595-TPS22916CNYFPR
IC3: R1200N001A-TR-FE; SOT95P280X110-6N; Manufacturer_Part_Number R1200N001A-TR-FE
J3: FH34SRJ-34S-0.5SH_50_; FH34SRJ34S05SH50; Mouser Part Number 798-FH34SRJ34S05SH50
L4: 10u; L_1812_4532Metric
R12: 100k; R_0402_1005Metric
R13: 200k; R_0402_1005Metric
R14: 220k; R_0402_1005Metric
R15: 15k; R_0402_1005Metric
R16: 49.9R; R_0402_1005Metric
R17, R18: 10k; R_0402_1005Metric
R19: 1M5; R_0402_1005Metric
U6: MCP1700x-250xxTT; SOT-23

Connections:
+1V8: C41.1, C42.1, C43.1, J3.23, J3.24, R17.1, R18.1; also elsewhere on the board
/Display/17V_CE: IC3.1 (CE), R14.2
/Display/17V_VFB: IC3.6 (VFB), R12.1, R13.1, R15.1
/Display/17V_VFB_R: C32.2, R12.2
/Display/I_{REF}: J3.6, R19.2
/Display/LX4: IC3.4 (LX), L4.2
/Display/VBREF: C40.2, J3.29
/Display/VCOMH: C45.1, J3.3, J3.32
/Display/VSL: J3.28, R16.2
/Display/VSL_D: D4.2 (A), D5.1 (K)
/Display/VSL_R: D5.2 (A), R16.1
/Display_SPI_MOSI: J3.13; also elsewhere on the board
/Display_SPI_SCK: J3.14; also elsewhere on the board
//Display_SPI_CS: J3.19, R17.2; also elsewhere on the board
DISPLAY_3V3: C35.1, IC1.A1 (VOUT), U6.3 (VI)
DISPLAY_BATT_PWR: C33.1, IC2.A1 (VOUT), IC3.3 (VDD), L4.1, R14.1
DISPLAY_EN: IC1.B2 (ON), IC2.B2 (ON); also elsewhere on the board
DISPLAY_VCC: C32.1, C34.1, C44.1, C46.1, C47.1, IC3.2 (VOUT), J3.2, J3.33, R13.2
DISPLAY_VCI: C36.1, C37.1, C38.1, C39.1, J3.25, J3.26, J3.27, U6.2 (VO)
GND: C33.2, C34.2, C35.2, C36.2, C37.2, C38.2, C39.2, C40.1, C41.2, C42.2, C43.2, C44.2, C45.2, C46.2, C47.2, D4.1 (K), IC1.B1 (GND), IC2.B1 (GND), IC3.5 (GND), J3.4, J3.5, J3.7, J3.8, J3.9, J3.10, J3.11, J3.15, J3.16, J3.21, J3.22, J3.30, J3.31, R15.2, R19.1, U6.1 (GND); also elsewhere on the board
SYS_PWR: IC2.A2 (VIN); also elsewhere on the board
/DISPLAY_DATA_COMM: J3.17; also elsewhere on the board
/DISPLAY_RST: J3.18, R18.2; also elsewhere on the board

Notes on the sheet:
Ripple current = 0.5A, peak current = 0.35A Saturation Current LX4 >= 0.35A (use 1A)
Display PWR (ON/OFF)
V_{out}=V_{FB}×(R1+R2)/R1 V_{FB} = 1.238 1.238 * (1 + 200k/15k) = 17.03
Pin 8/9/10: Decoupling with Network in VCI section
3.3V -> 2.5V
Display Connector
29: R_{IREF} = (V_{IREF} - V_{SS}) / I_{REF} V_{IREF} = 17V - 3V I_{REF} = 10uA => R_{IREF} = (17V - 3V) / 10uA = 1M4 R => 1M5 about 7% dimmer 1M2 recommended by manufacturer 1M still within bounds but 223uA vs 149uA consumption
V_{CC} = 17V
V_{CI} = 2.5V

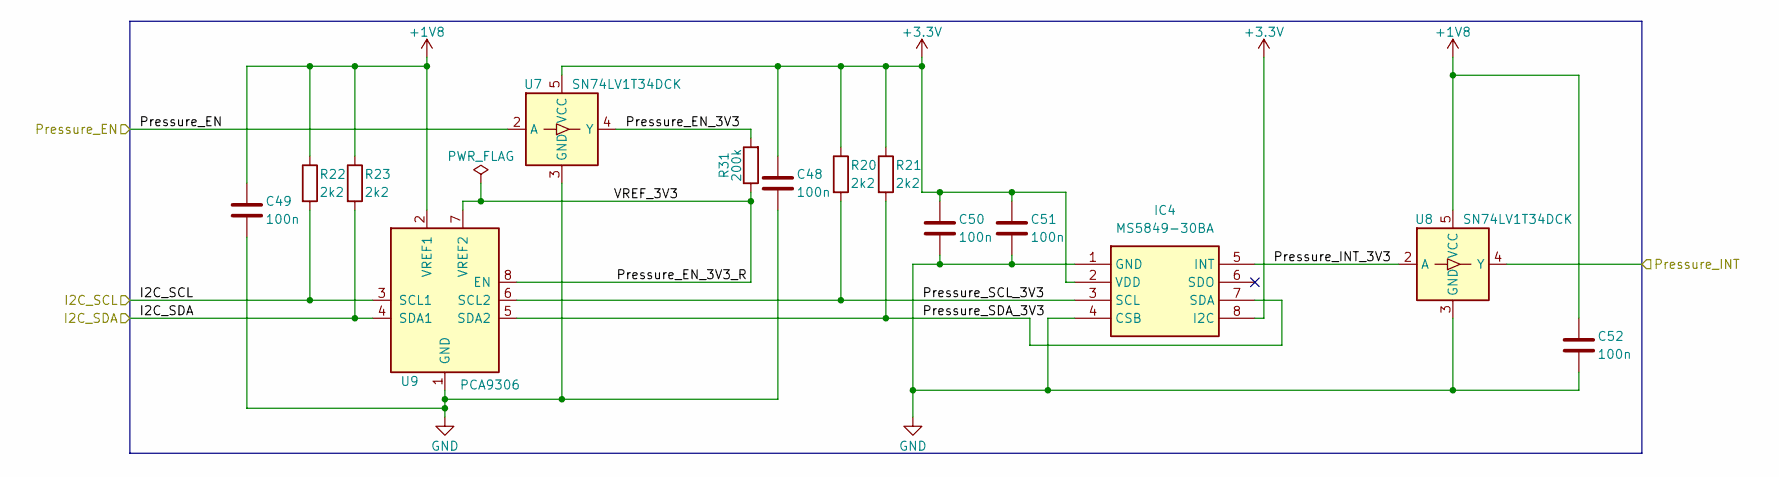
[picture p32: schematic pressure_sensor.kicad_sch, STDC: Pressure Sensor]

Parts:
C48, C49, C50, C51, C52: 100n; C_0402_1005Metric
IC4: MS5849-30BA; MS584930BA; Mouser Part Number 824-MS5849-30BA
R20, R21, R22, R23: 2k2; R_0402_1005Metric
R31: 200k; R_0402_1005Metric
U7, U8: SN74LV1T34DCK; SOT-353_SC-70-5
U9: PCA9306; X2SON-8_1.4x1mm_P0.35mm

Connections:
+1V8: C49.1, C52.1, R22.1, R23.1, U8.5 (VCC), U9.2 (VREF1); also elsewhere on the board
/Pressure Sensor/I2C_SCL: R22.2, U9.3 (SCL1); also elsewhere on the board
/Pressure Sensor/I2C_SDA: R23.2, U9.4 (SDA1); also elsewhere on the board
/Pressure Sensor/Pressure_EN: U7.2 (A); also elsewhere on the board
/Pressure Sensor/Pressure_INT: U8.4 (Y); also elsewhere on the board
/Pressure Sensor/Pressure_INT_3V3: IC4.5 (INT), U8.2 (A)
/Pressure Sensor/Pressure_SCL_3V3: IC4.3 (SCL), R20.2, U9.6 (SCL2)
/Pressure Sensor/Pressure_SDA_3V3: IC4.7 (SDA), R21.2, U9.5 (SDA2)
GND: C48.2, C49.2, C50.2, C51.2, C52.2, IC4.1 (GND), IC4.4 (CSB), U7.3 (GND), U8.3 (GND), U9.1 (GND); also elsewhere on the board

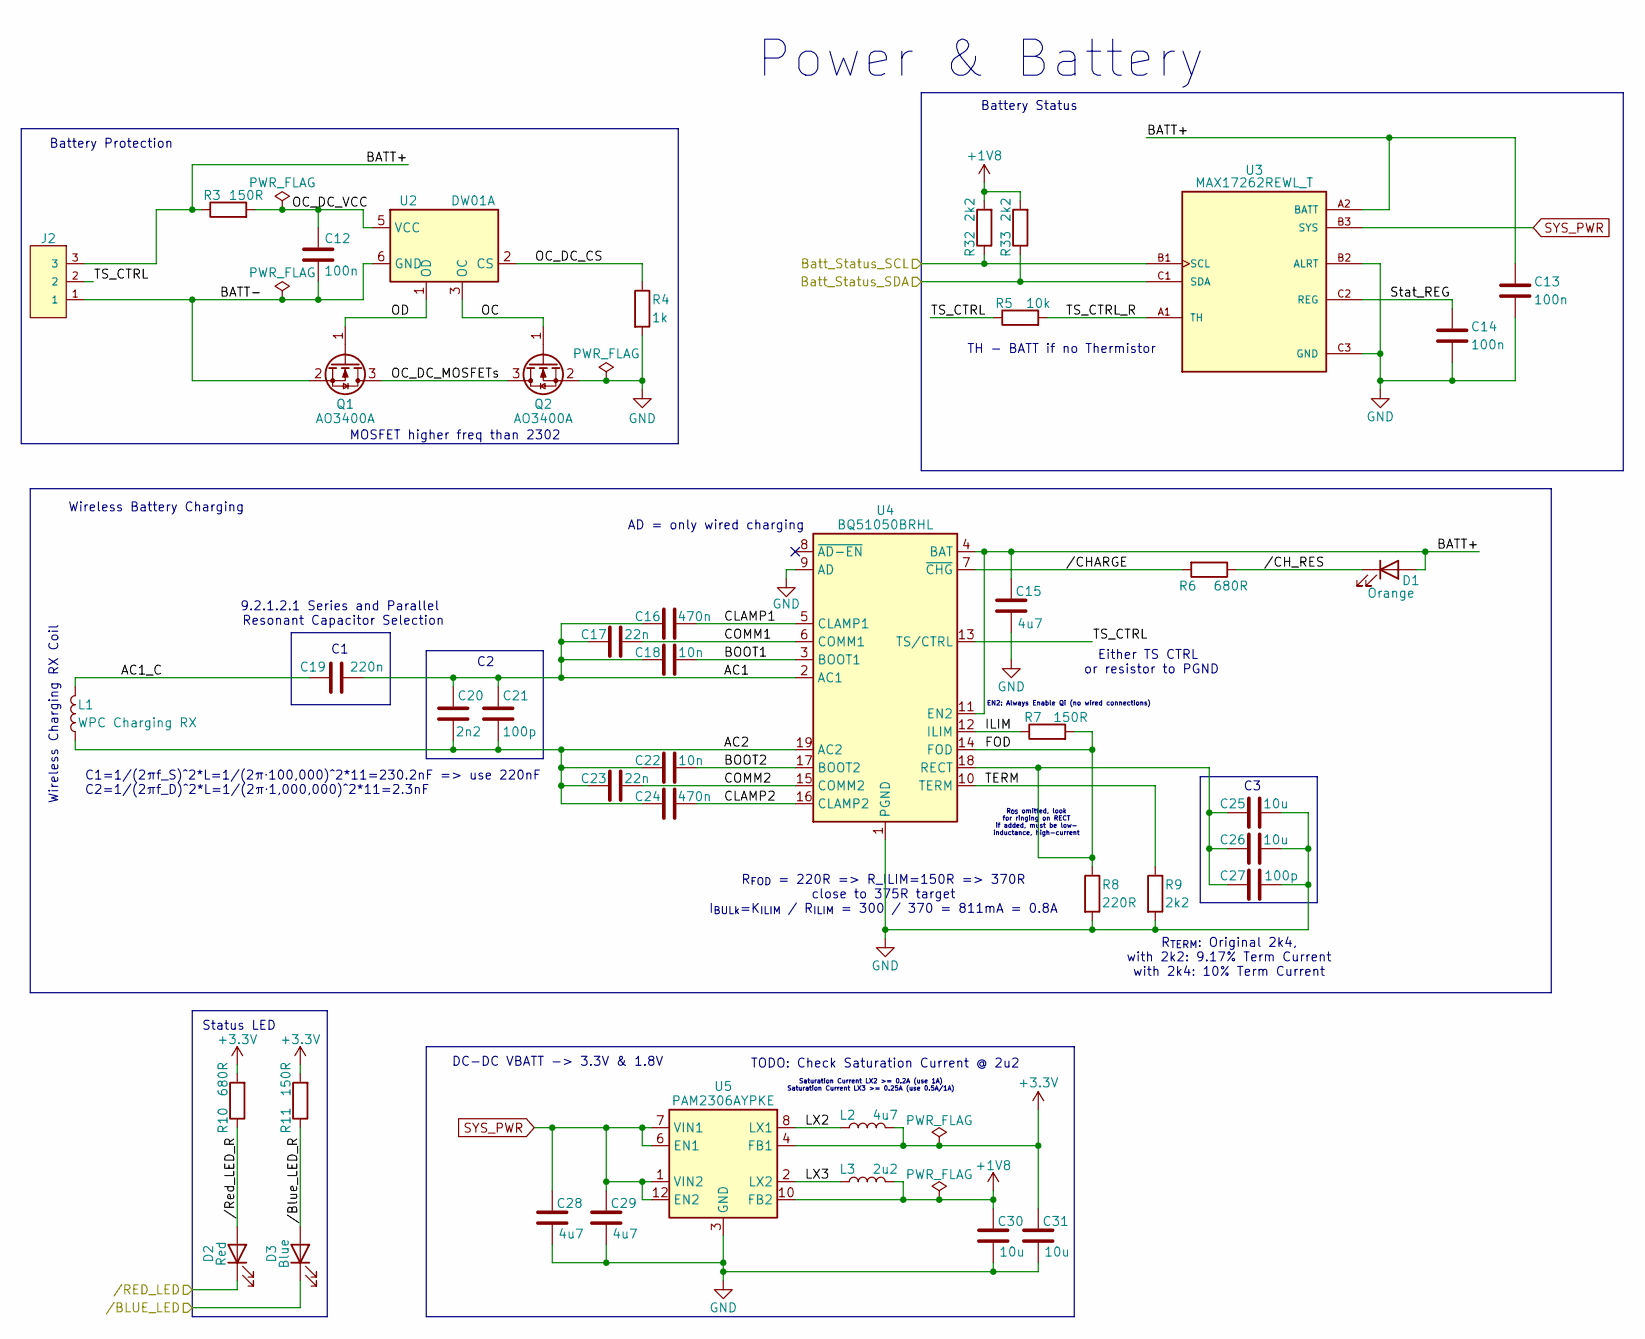
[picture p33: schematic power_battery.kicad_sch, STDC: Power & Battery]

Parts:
C12, C13, C14: 100n; C_0402_1005Metric
C15, C28, C29: 4u7; C_0402_1005Metric
C16, C24: 470n; C_0402_1005Metric
C17, C23: 22n; C_0402_1005Metric
C18, C22: 10n; C_0402_1005Metric
C19: 220n; C_0402_1005Metric
C20: 2n2; C_0402_1005Metric
C21, C27: 100p; C_0402_1005Metric
C25, C26, C30, C31: 10u; C_0402_1005Metric
D1: Orange; LED_0603_1608Metric
D2: Red; LED_0603_1608Metric
D3: Blue; LED_0603_1608Metric
J2: S3B-PH-SM4-TB_LF__SN_; JST_S3B-PH-SM4-TB_LF__SN_; PARTREV NA
L1: WPC Charging RX; L_IWAS4832ABEB110JF1
L2: 4u7; L_1210_3225Metric
L3: 2u2; L_1210_3225Metric
Q1, Q2: AO3400A; SOT-23
R3, R7, R11: 150R; R_0402_1005Metric
R4: 1k; R_0402_1005Metric
R5: 10k; R_0402_1005Metric
R6, R10: 680R; R_0402_1005Metric
R8: 220R; R_0402_1005Metric
R9, R32, R33: 2k2; R_0402_1005Metric
U2: DW01A; SOT-23-6
U3: MAX17262REWL_T; BGA9N40P3X3_144X146X69N
U4: BQ51050BRHL; Texas_VQFN-RHL-20
U5: PAM2306AYPKE; WDFN-12-1EP_3x3mm_P0.45mm_EP1.7x2.5mm

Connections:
+1V8: C30.1, L3.2, R32.2, R33.2, U5.10 (FB2); also elsewhere on the board
/Power+Battery/AC1: C16.1, C17.1, C18.1, C19.2, C20.1, C21.1, U4.2 (AC1)
/Power+Battery/AC1_C: C19.1, L1.2
/Power+Battery/AC2: C20.2, C21.2, C22.1, C23.1, C24.1, L1.1, U4.19 (AC2)
/Power+Battery/BATT+: C13.1, C15.1, D1.2 (A), J2.3, R3.1, U3.A2 (BATT), U4.4 (BAT), U4.11 (EN2)
/Power+Battery/BATT-: C12.2, J2.1, Q1.2 (S), U2.6 (GND)
/Power+Battery/BOOT1: C18.2, U4.3 (BOOT1)
/Power+Battery/BOOT2: C22.2, U4.17 (BOOT2)
/Power+Battery/Batt_Status_SCL: R32.1, U3.B1 (SCL); also elsewhere on the board
/Power+Battery/Batt_Status_SDA: R33.1, U3.C1 (SDA); also elsewhere on the board
/Power+Battery/CLAMP1: C16.2, U4.5 (CLAMP1)
/Power+Battery/CLAMP2: C24.2, U4.16 (CLAMP2)
/Power+Battery/COMM1: C17.2, U4.6 (COMM1)
/Power+Battery/COMM2: C23.2, U4.15 (COMM2)
/Power+Battery/FOD: C25.1, C26.1, C27.1, R7.2, R8.1, U4.14 (FOD), U4.18 (RECT)
/Power+Battery/ILIM: R7.1, U4.12 (ILIM)
/Power+Battery/LX2: L2.1, U5.8 (LX1)
/Power+Battery/LX3: L3.1, U5.2 (LX2)
/Power+Battery/OC: Q2.1 (G), U2.3 (OC)
/Power+Battery/OC_DC_CS: R4.1, U2.2 (CS)
/Power+Battery/OC_DC_MOSFETs: Q1.3 (D), Q2.3 (D)
/Power+Battery/OC_DC_VCC: C12.1, R3.2, U2.5 (VCC)
/Power+Battery/OD: Q1.1 (G), U2.1 (OD)
/Power+Battery/Stat_REG: C14.1, U3.C2 (REG)
/Power+Battery/TERM: R9.1, U4.10 (TERM)
/Power+Battery/TS_CTRL: J2.2, R5.1, U4.13 (TS/CTRL)
/Power+Battery/TS_CTRL_R: R5.2, U3.A1 (TH)
/Power+Battery//BLUE_LED: D3.1 (K); also elsewhere on the board
/Power+Battery//Blue_LED_R: D3.2 (A), R11.1
/Power+Battery//CHARGE: R6.2, U4.7 (~CHG)
/Power+Battery//CH_RES: D1.1 (K), R6.1
/Power+Battery//RED_LED: D2.1 (K); also elsewhere on the board
/Power+Battery//Red_LED_R: D2.2 (A), R10.1
GND: C13.2, C14.2, C15.2, C25.2, C26.2, C27.2, C28.2, C29.2, C30.2, C31.2, Q2.2 (S), R4.2, R8.2, R9.2, U3.B2 (ALRT), U3.C3 (GND), U4.1 (PGND), U4.9 (AD), U4.20 (PGND), U4.21 (PGND), U5.3 (GND), U5.9 (GND), U5.13 (GND); also elsewhere on the board
SYS_PWR: C28.1, C29.1, U3.B3 (SYS), U5.1 (VIN2), U5.6 (EN1), U5.7 (VIN1), U5.12 (EN2); also elsewhere on the board

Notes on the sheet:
Power & Battery
Wireless Battery Charging
DC-DC VBATT -> 3.3V & 1.8V
C2 =1/(2πf_D )^2*L =1/(2π⋅1,000,000)^2*11=2.3nF
R_{FOD} = 220R => R_ILIM=150R => 370R close to 375R target I_{BULk}=K_{ILIM} / R_{ILIM} = 300 / 370 = 811mA = 0.8A
Status LED
C1 =1/(2πf_S )^2*L =1/(2π⋅100,000)^2*11=230.2nF => use 220nF
Either TS CTRL or resistor to PGND
Wireless Charging RX Coil
MOSFET higher freq than 2302
R_{TERM}: Original 2k4, with 2k2: 9.17% Term Current with 2k4: 10% Term Current
Saturation Current LX2 >= 0.2A (use 1A) Saturation Current LX3 >= 0.25A (use 0.5A/1A)
9.2.1.2.1 Series and Parallel Resonant Capacitor Selection
TODO: Check Saturation Current @ 2u2
TH - BATT if no Thermistor
Battery Protection
AD = only wired charging
R_{OS} omitted, look for ringing on RECT if added, must be low- inductance, high-current
Battery Status
EN2: Always Enable Qi (no wired connections)

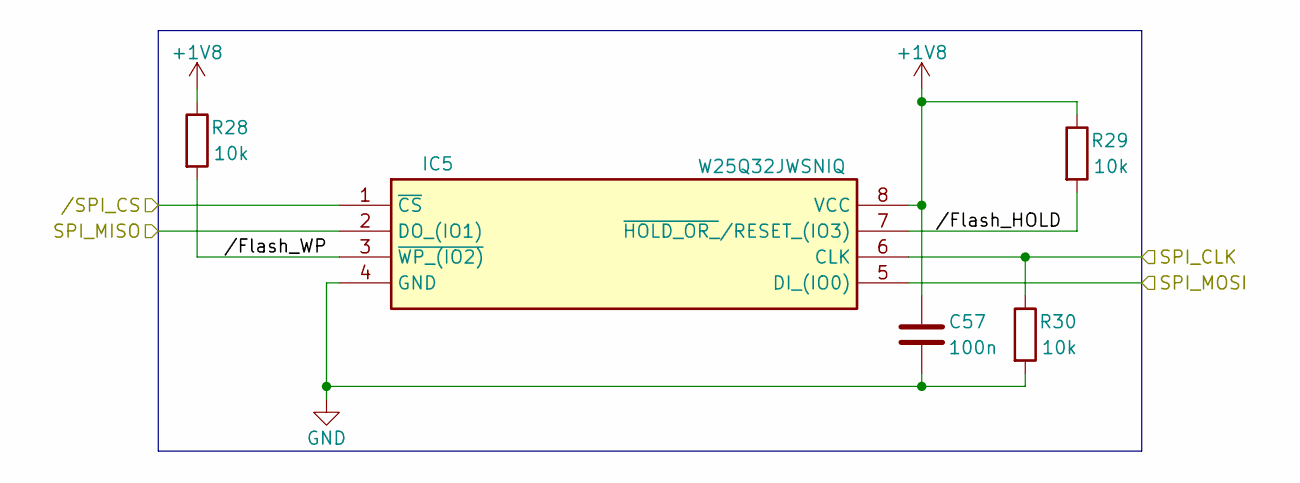
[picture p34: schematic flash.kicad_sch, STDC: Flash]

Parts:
C57: 100n; C_0402_1005Metric
IC5: W25Q32JWSNIQ; SOIC127P600X175-8N; Manufacturer_Part_Number W25Q32JWSNIQ; Mouser Part Number 454-W25Q32JWSNIQ
R28, R29, R30: 10k; R_0402_1005Metric

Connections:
+1V8: C57.1, IC5.8 (VCC), R28.1, R29.1; also elsewhere on the board
/Flash//Flash_HOLD: IC5.7 (~HOLD_OR_/RESET_(IO3)), R29.2
/Flash//Flash_WP: IC5.3 (~WP_(IO2)), R28.2
/SPI_CLK: IC5.6 (CLK), R30.1; also elsewhere on the board
/SPI_MISO: IC5.2 (DO_(IO1)); also elsewhere on the board
/SPI_MOSI: IC5.5 (DI_(IO0)); also elsewhere on the board
/SPI_NSS: IC5.1 (~CS); also elsewhere on the board
GND: C57.2, IC5.4 (GND), R30.2; also elsewhere on the board

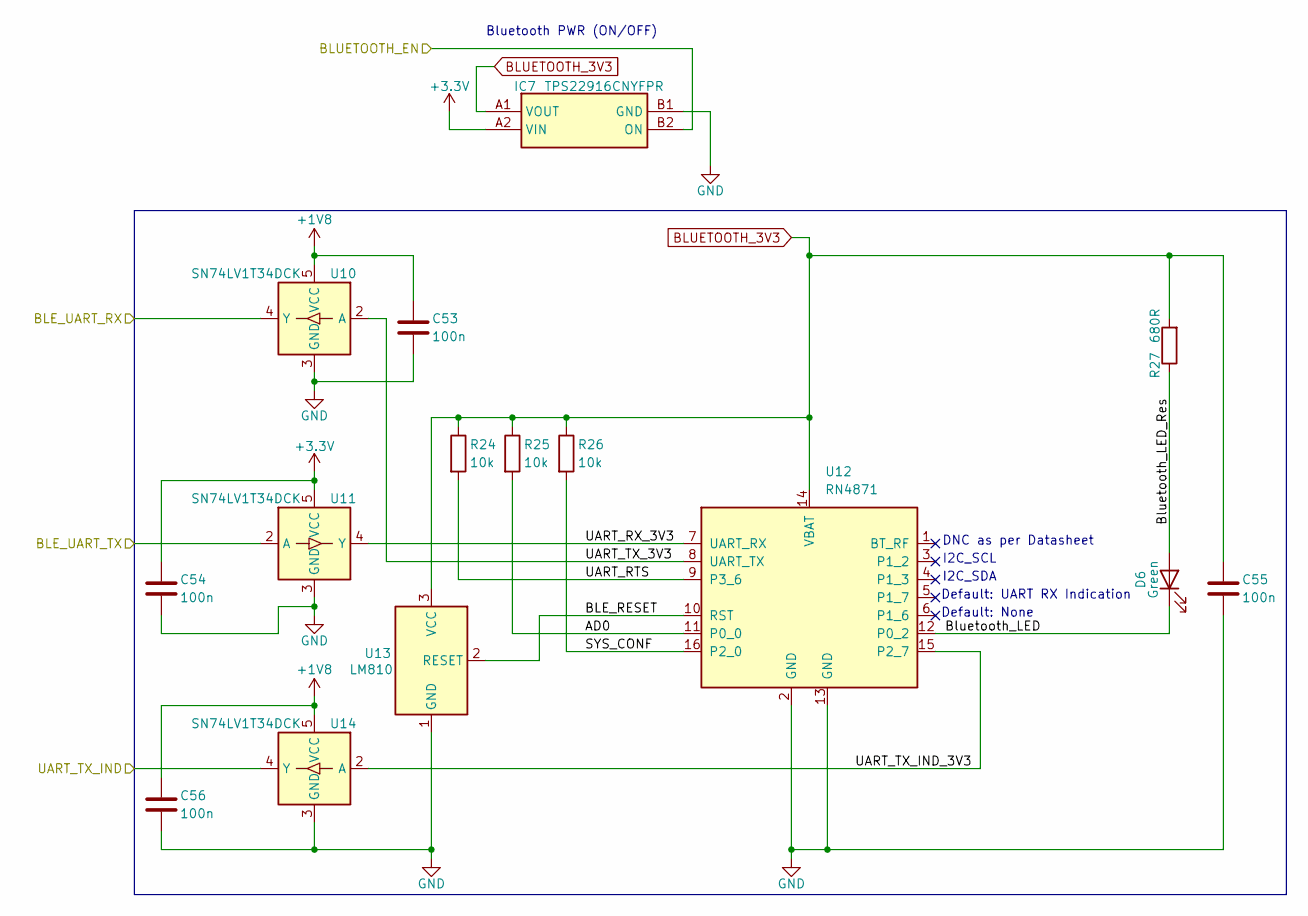
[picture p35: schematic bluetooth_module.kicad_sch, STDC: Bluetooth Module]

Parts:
C53, C54, C55, C56: 100n; C_0402_1005Metric
D6: Green; LED_0603_1608Metric
IC7: TPS22916CNYFPR; BGA4C40P2X2_78X78X50; Mouser Part Number 595-TPS22916CNYFPR
R24, R25, R26: 10k; R_0402_1005Metric
R27: 680R; R_0402_1005Metric
U10, U11, U14: SN74LV1T34DCK; SOT-353_SC-70-5
U12: RN4871; Microchip_RN4871
U13: LM810; SOT-23

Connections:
+1V8: C53.1, C56.1, U10.5 (VCC), U14.5 (VCC); also elsewhere on the board
/BLE_TX_IND: U14.4 (Y); also elsewhere on the board
/Bluetooth Module/AD0: R25.2, U12.11 (P0_0)
/Bluetooth Module/BLE_RESET: U12.10 (RST), U13.2 (RESET)
/Bluetooth Module/BLE_UART_RX: U10.4 (Y); also elsewhere on the board
/Bluetooth Module/BLE_UART_TX: U11.2 (A); also elsewhere on the board
/Bluetooth Module/Bluetooth_LED: D6.1 (K), U12.12 (P0_2)
/Bluetooth Module/Bluetooth_LED_Res: D6.2 (A), R27.1
/Bluetooth Module/SYS_CONF: R26.2, U12.16 (P2_0)
/Bluetooth Module/UART_RTS: R24.2, U12.9 (P3_6)
/Bluetooth Module/UART_RX_3V3: U11.4 (Y), U12.7 (UART_RX)
/Bluetooth Module/UART_TX_3V3: U10.2 (A), U12.8 (UART_TX)
/Bluetooth Module/UART_TX_IND_3V3: U12.15 (P2_7), U14.2 (A)
GND: C53.2, C54.2, C55.2, C56.2, IC7.B1 (GND), U10.3 (GND), U11.3 (GND), U12.2 (GND), U12.13 (GND), U13.1 (GND), U14.3 (GND); also elsewhere on the board

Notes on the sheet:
Default: UART RX Indication
DNC as per Datasheet
Default: None
I2C_SCL
Bluetooth PWR (ON/OFF)
I2C_SDA

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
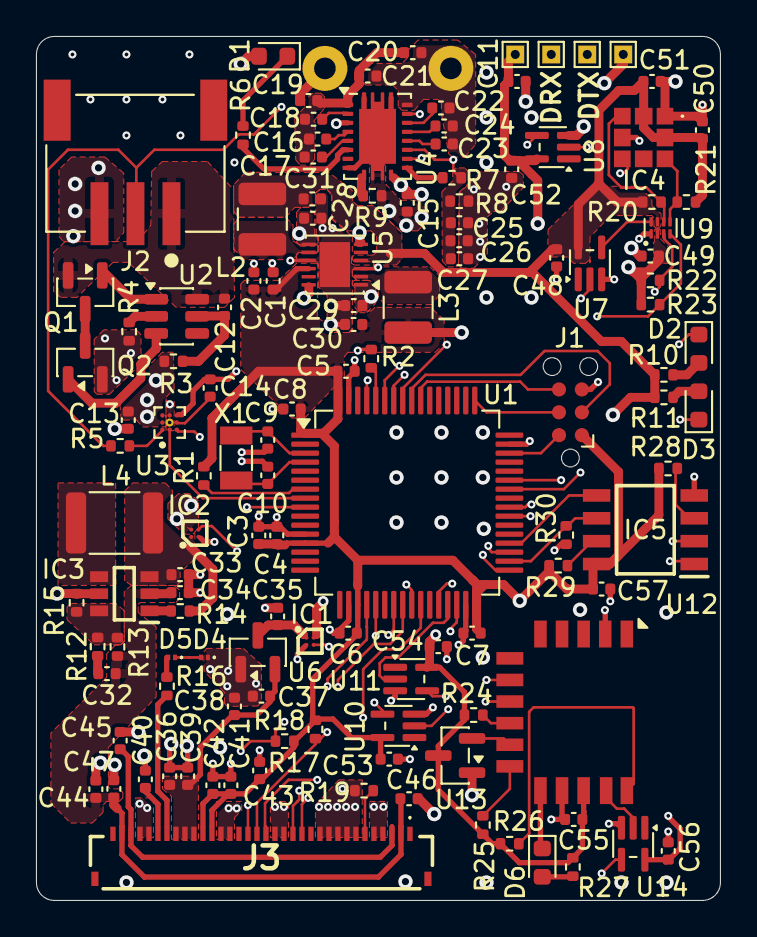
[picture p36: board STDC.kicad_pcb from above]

Board: 4 copper layers, 38.0 x 48.0 mm, 126 parts (0 on the bottom side), 92 nets.

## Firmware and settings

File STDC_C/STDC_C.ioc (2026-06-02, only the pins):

Mcu.UserName=STM32L476RGTx
PA1.GPIO_Label=Button
PA1.Signal=GPXTI1
PA10.Signal=USART1_RX
PA4.GPIO_Label=_SPI1_CS
PA4.Signal=GPIO_Output
PA5.Signal=SPI1_SCK
PA7.Signal=SPI1_MOSI
PA9.Signal=USART1_TX
PB0.GPIO_Label=_DISPLAY_DATA_COMM
PB0.Signal=GPIO_Output
PB1.GPIO_Label=Bluetooth_EN
PB1.Signal=GPIO_Output
PB10.Signal=USART3_TX
PB11.Signal=USART3_RX
PB12.Signal=SPI2_NSS
PB13.Signal=SPI2_SCK
PB14.Signal=SPI2_MISO
PB15.Signal=SPI2_MOSI
PB2.GPIO_Label=UART_TX_IND
PB2.Signal=GPIO_Input
PB5.GPIO_Label=PRESSURE_INT
PB5.Signal=GPXTI5
PB6.Signal=I2C1_SCL
PB7.Signal=I2C1_SDA
PB8.GPIO_Label=PRESSURE_EN
PB8.Signal=GPIO_Output
PC0.Signal=I2C3_SCL
PC1.Signal=I2C3_SDA
PC4.GPIO_Label=_SPI_RST
PC4.Signal=GPIO_Output
PC5.GPIO_Label=Display_EN
PC5.Signal=GPIO_Output
PC8.GPIO_Label=_Blue_LED
PC8.Signal=GPIO_Output
PC9.GPIO_Label=_Red_LED
PC9.Signal=GPIO_Output

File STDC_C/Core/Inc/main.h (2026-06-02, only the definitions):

#define _SPI1_CS_Pin GPIO_PIN_4
#define _SPI1_CS_GPIO_Port GPIOA
#define _SPI_RST_Pin GPIO_PIN_4
#define _SPI_RST_GPIO_Port GPIOC
#define Display_EN_Pin GPIO_PIN_5
#define Display_EN_GPIO_Port GPIOC
#define _DISPLAY_DATA_COMM_Pin GPIO_PIN_0
#define _DISPLAY_DATA_COMM_GPIO_Port GPIOB
#define UART_TX_IND_Pin GPIO_PIN_2
#define UART_TX_IND_GPIO_Port GPIOB
#define _Blue_LED_Pin GPIO_PIN_8
#define _Blue_LED_GPIO_Port GPIOC
#define _Red_LED_Pin GPIO_PIN_9
#define _Red_LED_GPIO_Port GPIOC
#define PRESSURE_INT_Pin GPIO_PIN_5
#define PRESSURE_INT_GPIO_Port GPIOB
#define PRESSURE_EN_Pin GPIO_PIN_8
#define PRESSURE_EN_GPIO_Port GPIOB

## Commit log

2026-03-04 KiCad Project: Draft 01
    [STDC.kicad_pcb, STDC.kicad_sch, bluetooth_module.kicad_sch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]
2026-03-04 Add Power Flag on GND
    [power_battery.kicad_sch]
2026-03-05 Create Revision 0.0.1
    [STDC.kicad_sch, bluetooth_module.kicad_sch, display.kicad_sch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]
2026-03-05 Add TODO to discuss tomorrow
    [power_battery.kicad_sch]
2026-03-05 Add decoupling for external connectors
    [STDC.kicad_sch]
2026-03-06 Added some TODOs, fixed some TODOs
    [STDC.kicad_sch, bluetooth_module.kicad_sch, display.kicad_sch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]
2026-03-06 Fix JTAG connector
    [STDC.kicad_sch, power_battery.kicad_sch]
2026-03-08 Testing connectors, SPI2 pinout, reannotate
    [STDC.kicad_sch, bluetooth_module.kicad_sch, display.kicad_sch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]
2026-03-08 Calculate saturation current for coils and add comments
    [bluetooth_module.kicad_sch, display.kicad_sch, flash.kicad_sch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]
2026-03-08 Add todos
    [bluetooth_module.kicad_sch, flash.kicad_sch]
2026-03-08 Add Pull-Down on SPI Flash Clk as per STM32 Bootloader datasheet Rev 70/page 49
    [flash.kicad_sch]
2026-03-08 Fix display Rs to fix 17V reference and consolidate BOM
    And add more info to R_{IREF}
    [STDC.kicad_sch, display.kicad_sch, power_battery.kicad_sch]
2026-03-09 Organize components in power and display, setup PCB
    [STDC.kicad_pcb, STDC.kicad_sch, bluetooth_module.kicad_sch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]
2026-03-09 Use JLCPCB setup ported from Altium
    https://gitlab.ethz.ch/villanif/altium_files/-/tree/master/example_design_rules
    [STDC.kicad_pcb]
2026-03-10 First Draft PCB Layout
    [STDC.kicad_pcb, STDC.kicad_sch, bluetooth_module.kicad_sch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]
2026-03-12 Implement Comments, Working on PCB Layout
    [STDC.kicad_pcb, STDC.kicad_sch, bluetooth_module.kicad_sch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]
2026-03-14 PCB Layout V0.1 with errors
    [STDC.kicad_pcb, STDC.kicad_sch, bluetooth_module.kicad_sch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]
2026-03-14 Fix almost all issues
    [STDC.kicad_pcb]
2026-03-14 Fix all except clearance violations
    [STDC.kicad_pcb]
2026-03-14 Some track spacing
    [STDC.kicad_pcb]
2026-03-14 Power Regulator Layout Adjustment
    [STDC.kicad_pcb]
2026-03-14 A bit more space for the connector
    [STDC.kicad_pcb]
2026-03-14 Reimport from schematic
    [STDC.kicad_pcb]
2026-03-14 Fix GND vias
    [STDC.kicad_pcb]
2026-03-14 Smaller pad
    [STDC.kicad_pcb]
2026-03-14 More space for Connector
    [STDC.kicad_pcb]
2026-03-15 Use SMD SM4 Connector for JST PH Battery
    [STDC.kicad_pcb]
2026-03-15 Fix Schematic Symbol Footprint Filter from Library for Battery
    [STDC.kicad_pcb, power_battery.kicad_sch]
2026-03-15 More space for power planes, traces
    [STDC.kicad_pcb]
2026-03-15 Display VCC more space
    [STDC.kicad_pcb]
2026-03-15 Wider power traces
    [STDC.kicad_pcb]
2026-03-15 Move Logo
    [STDC.kicad_pcb]
2026-03-15 Polarity Silkscreen
    [STDC.kicad_pcb]
2026-03-15 Easier VIA placement
    [STDC.kicad_pcb]
2026-03-16 Use SMT connector for Battery
    [STDC.kicad_pcb, power_battery.kicad_sch]
2026-03-22 Fix polarity of Bluetooth Status LED
    [STDC.kicad_pcb, bluetooth_module.kicad_sch]
2026-03-22 Reduce Cuts in reference plane
    [STDC.kicad_pcb]
2026-03-22 Fewer GND cuts, 1.8V Routing for Pressure INT
    [STDC.kicad_pcb]
2026-04-07 Move Connector down, fix silkscreen clearance errors, Stitching Vias for GND
    [STDC.kicad_pcb]
2026-04-07 Generate output files with 0 mask expansion
    [STDC.kicad_pcb]
2026-04-08 Update Libs for connector etc
    [STDC.kicad_pcb, display.kicad_sch]
2026-04-11 Ordering V1
    [STDC-B_Cu.gbr, STDC-B_Mask.gbr, STDC-B_Paste.gbr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]
2026-06-02 Add STDC-STM32-rs submodule
2026-06-17 V2 beginning with buttons, resistor, ...
    [STDC.kicad_pcb, STDC.kicad_sch, bluetooth_module.kicad_sch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]
2026-06-17 Display inverted
    [display.kicad_sch]
2026-06-17 Remove KiCad and STDC-ORdering
    [STDC-B_Cu.gbr, STDC-B_Mask.gbr, STDC-B_Paste.gbr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]
2026-06-17 Add PCB Submodule

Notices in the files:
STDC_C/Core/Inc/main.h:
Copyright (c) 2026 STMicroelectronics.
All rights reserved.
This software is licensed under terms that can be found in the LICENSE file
